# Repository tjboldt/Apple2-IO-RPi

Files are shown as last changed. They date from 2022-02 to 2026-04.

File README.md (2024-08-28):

# Apple2-IO-RPi
Apple II expansion card using a Raspberry Pi for I/O

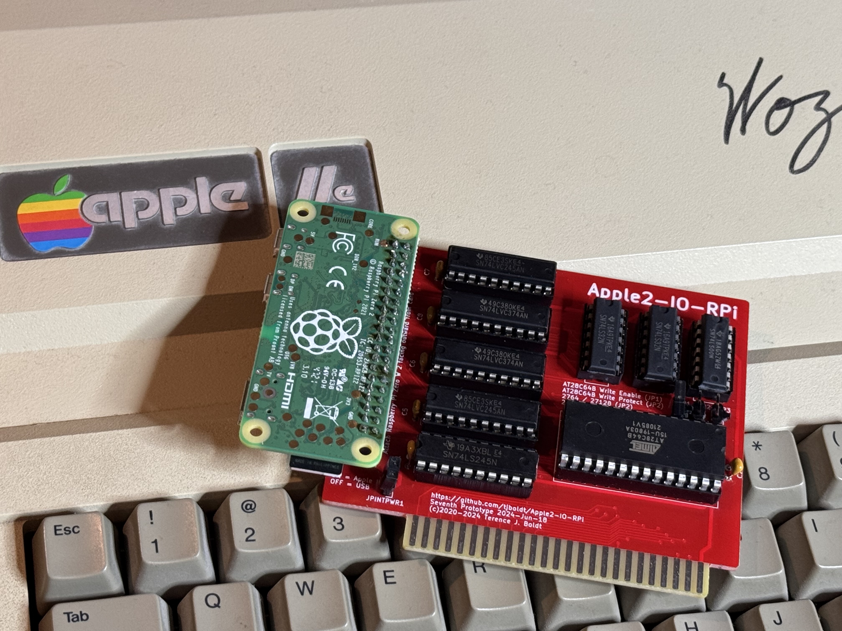
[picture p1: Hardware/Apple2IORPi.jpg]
Image of Board


## Purpose
The purpose of this project is to provide I/O for an Apple II series 8 bit computer via a Raspberry Pi Zero 2 W which is powered by the Apple II expansion bus. This includes using the attached RPi Zero 2 W for it's storage, network and processor to provide new functionality for the Apple II.

## Features
1. Boot message which waits for RPi to be ready
2. ProDOS bootable drive from image stored on RPi
3. Linux bash shell to the RPi from the Apple II including some VT100 support via `-SHELL` from ProDOS
4. Load binary files directly from the RPi to the II (via dynamic virtual drive of current working directory on the RPi)
5. Update Apple II firmware in place from image on RPi (note, this is done per slot)
6. Supports two drive images at the same time
7. Supports "RPI" command from BASIC to execute Linux commands from the command prompt or inside BASIC programs: `10 PRINT CHR$(4);"RPI ls -al /"`

## Project Status

### Classic Hardware
So far, this is still a project and not a finished product. The current prototype is on the seventh revision. I have sold about 60 boards including previous prototypes. There are several hundred in the wild between self made and ones purchased in places like eBay that were made by others. The seventh prototype is functionally equivalent to the sixth other than support for write-protect and reintroducing EPROM support. The fifth revision was similar and compatible with the sixth, other than a new jumper to select internal/external power on the sixth.

The card enables the Apple II to boot from and write to virtual hard drive images stored on the RPi in any slot (except slot 3), execute Linux commands from Applesoft BASIC and run a bash shell with VT100 emulation. The code has very few tests and is incomplete. Note that currently the firmware assumes an 80 column card is in slot 3 and than you have lowercase support. Most development has been done with an enhanced Apple //e with the card in slot 7. If you have other drive controllers earlier in the boot cycle, you can still boot from the Apple2-IO-RPi. For example, if the card was in slot 4, you could type `PR#4` from the BASIC prompt to boot the card. Note that the Raspberry Pi Zero W (and W 2) consume 170 - 250 mA and there is only 500 mA available to all expansion slots according to Apple. It is not recommended to have a lot of other cards in the system at the same time. With the sixth revision of the prototype, it is possible to remove the power jumper and run the RPi on an external USB power source. If configured for external power, note that the card's firmware will hang on boot without USB power on as the latch chips are powered by the 3.3V output of the RPi. 

If you have a problem or idea for enhancement, log an issue [here](https://github.com/tjboldt/Apple2-IO-RPi/issues) or start a [discussion](https://github.com/tjboldt/Apple2-IO-RPi/discussions/categories/general). I recommend starring/watching the project for updates on GitHub. You are welcome to fork the project and submit pull requests which I will review. The latest version has an in-memory virtual drive representing current working directory in Linux for ease of copying files between Linux and ProDOS when the drive 1 is not specified as a file.

### Pico Hardware
Ralle Palaveev has a version of the hardware that uses a RPi Pico to handle firmware and communications to the host over USB. This uses Oliver Schmidt's PIO code.

## Roadmap
See [List of issues tagged roadmap](https://github.com/tjboldt/Apple2-IO-RPi/issues?q=is%3Aissue+is%3Aopen+label%3Aroadmap+author%3Atjboldt) 

## Setup on classic hardware
[Setup card from scratch](/ClassicSetup.md)

[Update to latest](https://github.com/tjboldt/Apple2-IO-RPi/discussions/65)

## Setup on Pico based hardware
[Setup card with Pico hardware](/PicoSetup.md)

## Contributions/Thanks
- Hans Hübner ([@hanshuebner](https://github.com/hanshuebner)) for help cleaning up schematics
- Scott ([@figital](https://github.com/figital)) for assembling early prototypes and recommending the AT28C64B chip
- Brokencodez for help with 3.3V conversion
- David Schmenk ([@dschmenk](https://github.com/dschmenk)) for creating his Apple2Pi project, proving that Raspberry Pi can be powered by the Apple II expansion bus
- Wyatt Wong ([@wyatt-wong](https://github.com/wyatt-wong)) for testing with multiple cards
- ([@Abysmal](https://github.com/Abysmal)) for shell and rpi.command testing
- ([@bfranske](https://github.com/bfranske)) for suggesting adding the 5V jumper
- Tim Boldt ([@timboldt](https://github.com/timboldt)) for recommending removing sysfs based GPIO code
- Oliver Schmidt ([@oliverschmidt](https://github.com/oliverschmidt/a2pico)) for writing the Pico PIO and firmware
- Ralle Palaveev ([@rallepalaveev](https://github.com/rallepalaveev)) for Pico hardware design
- Seth Kushniryk ([@sethkush](https://github.com/sethkush)) for providing information on meta key support for shell

## Similar Project
If you prefer having Apple II peripherals control a Raspberry Pi rather than simply using the Raspberry Pi to provide storage, network access and processing to the Apple II, have a look at David Schmenk's excellent [Apple2Pi](https://github.com/dschmenk/apple2pi) project. I am often asked about differences between these two projects. They are similar in some ways but essentially opposite. The Apple2Pi is meant for the primary machine to be the RPi, using the Apple II for it's peripherals. The Apple2-IO-RPi is meant to have the Apple II as the primary machine and just use the RPi for its processing, storage and network.

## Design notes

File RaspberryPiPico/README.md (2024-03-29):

The setup.sh and build.sh are here for convenience of building the Pico code directly on the RPi Zero 2 W attached to the Apple II.

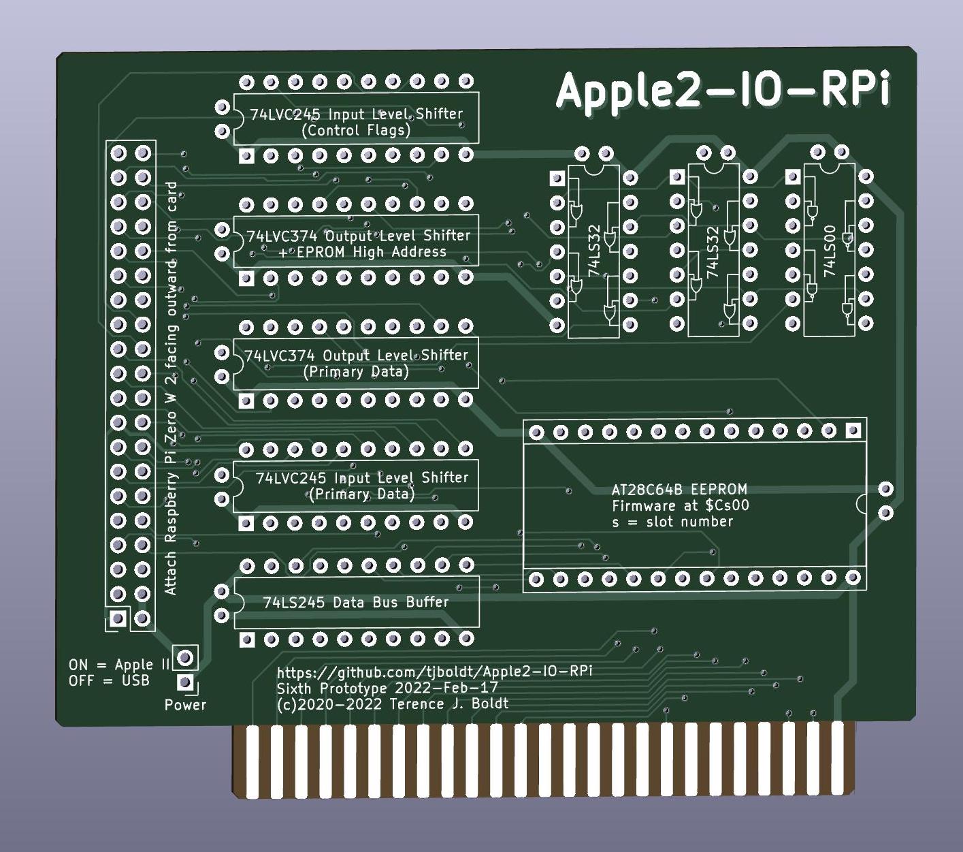
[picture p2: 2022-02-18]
Hardware/Apple2IORPi_PCB.jpg

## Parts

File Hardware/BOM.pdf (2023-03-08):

### Apple2-IO-RPi v5/v6 Bill of Materials

Part | Quantity | Supplier Part # | Supplier
74LS32 | 2 | 595-SN74LS32N | Mouser
74LS00 | 1 | 595-SN74LS00N | Mouser
74LS245 | 1 | 595-SN74LS245N | Mouser
74LVC245 | 2 | 595-SN74LVC245AN | Mouser
74LVC374 | 2 | 595-SN74LVC374AN | Mouser
28C64B | 1 | 556-AT28C64B15PU | Mouser
0.1µF Capacitor | 9 | 594-K104K15X7RF5TH5 | Mouser
2x20 GPIO Female Header | 1 | 2222 | Adafruit
14 Pin DIP Socket | 3 | 571-1-2199298-3 | Mouser
20 Pin DIP Socket | 5 | 571-1-2199298-6 | Mouser
28 Pin DIP Socket | 1 | 571-1-2199299-2 | Mouser

1

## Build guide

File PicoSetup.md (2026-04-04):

## Setup starting from scratch
This is for the A2Pico board (https://github.com/oliverschmidt/a2pico)
1. DIY instructions and PCB coming but it is recommended to buy a board from Ralle Palaveev
2. Update the Pico firmware using the .uf2 file matching your hardware from https://github.com/tjboldt/Apple2-IO-RPi/releases/latest
3. Attach Raspberry Pi Zero 2 W with a micro USB OTG cable
4. Install [Raspberry Pi OS](https://www.raspberrypi.org/software/) on microSD card using a modern computer
    1. Use Raspberry Pi Imager
    2. Click "Choose OS"
    3. Select Other => "Raspberry Pi OS Lite (64 bit)" for the Zero 2 W
    4. Click on the gear icon in the bottom right
    5. Enable ssh
    6. Set password
    7. Configure wifi
    8. Set locale settings  
6. Put microSD card in the RPi
7. Install the expansion card into the Apple II
8. Power on the Apple II
9. Use `ssh` to connect to the RPi using the password you configured
10. `wget --no-cache -O - https://raw.githubusercontent.com/tjboldt/Apple2-IO-RPi/main/RaspberryPi/setup.sh | bash -s 1`

## Options
You can support two drives and change their drive images.
1. Modify the `ExecStart` line in `/etc/systemd/system/apple2driver.service` and make it something like the following: `ExecStart=/home/pi/Apple2-IO-RPi/RaspberryPi/apple2driver/apple2driver -cdc=true -d1 /home/pi/Apple2-IO-RPi/RaspberryPi/Apple2-IO-RPi.hdv -d2 /home/pi/Apple2-IO-RPi/RaspberryPi/TotalReplay401.hdv`
2. `sudo systemctl daemon-reload`
3. `sudo systemctl restart apple2driver.service`

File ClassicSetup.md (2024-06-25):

## Setup starting from scratch
1. Have PCBs made from [PCBWay](https://www.pcbway.com/project/shareproject/Apple2_IO_RPi_v7_65457a66.html) or from the gerber and drill files in the Hardware folder or email me for a blank or fully assembled board
2. Solder chips, header and capacitors in place
3. If you have an EPROM programmer, it is preferred to pre-populate the EEPROM with the contents of AT28C68B.bin
4. Attach Raspberry Pi Zero 2 W facing outward from the card
5. Install [Raspberry Pi OS](https://www.raspberrypi.org/software/) on microSD card using a modern computer
    1. Use Raspberry Pi Imager
    2. Click "Choose OS"
    3. Select Other => "Raspberry Pi OS Lite (64 bit)" for the Zero 2 W
    4. Click on the gear icon in the bottom right
    5. Enable ssh
    6. Set password
    7. Configure wifi
    8. Set locale settings  
6. Put microSD card in the RPi
7. Install the expansion card into the Apple II
8. Power on the Apple II
9. Only if you didn't have an EPROM programmer in step 3, install firmware with utility (can be found on Apple2-IO-RPi.hdv drive image in the release on GitHub) 
10. Use `ssh` to connect to the RPi using the password you configured
11. `wget --no-cache -O - https://raw.githubusercontent.com/tjboldt/Apple2-IO-RPi/main/RaspberryPi/setup.sh | bash`

## Options
You can support two drives and change their drive images.
1. Modify the `ExecStart` line in `/etc/systemd/system/apple2driver.service` and make it something like the following: `ExecStart=/home/pi/Apple2-IO-RPi/RaspberryPi/apple2driver/apple2driver -d1 /home/pi/Apple2-IO-RPi/RaspberryPi/Apple2-IO-RPi.hdv -d2 /home/pi/Apple2-IO-RPi/RaspberryPi/TotalReplay401.hdv`
2. `sudo systemctl daemon-reload`
3. `sudo systemctl restart apple2driver.service`

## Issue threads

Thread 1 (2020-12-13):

RPi service hangs if call interrupted

tjboldt, 2020-12-13:
If you reset the Apple II during a read or write operation, the RPi side hangs waiting for that to complete instead of timing out.

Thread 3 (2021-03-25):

GetTimeCommand called on each ReadBlock which is slow

tjboldt, 2021-03-25:
Ideally there should be a proper ProDOS clock driver but at a minimum, the GetTimeCommand should be called less frequently. Perhaps only reading block 0002 which the root directory is stored.

```
; ProDOS Read Block Command
ReadBlock:
 ldy #$00 ;Get the current time on each block read for now
 lda #GetTimeCommand
 jsr SendByte
getTimeByte:
 jsr GetByte
 sta $bf90,y
 iny
 cpy #$04
 bne getTimeByte
 lda #ReadBlockCommand ;read the block after setting the clock
```

tjboldt, 2021-05-10:
The firmware was updated to only get the time on reading block $0002.

Closed 2021-05-10.

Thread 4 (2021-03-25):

Slow power-on startup

tjboldt, 2021-03-25:
The Raspberry Pi needs to be configured to boot faster. Currently there is no startup optimization done.

tjboldt, 2022-02-09:
The boot time has been significantly reduced by using a Raspberry Pi Zero W 2 as well as the new instructions to disable unnecessary services in the setup: https://github.com/tjboldt/Apple2-IO-RPi/discussions/63

Closed 2022-02-09.

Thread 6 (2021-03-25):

Rpi.Command is hard coded for slot 5 operation

tjboldt, 2021-03-25:
This code was written in the mini assembler on an enhanced Apple //e as a quick test so it was lazily hard coded for slot 5. This should be updated to detect the card automatically in any slot.

tjboldt, 2021-03-28:
Command was removed and code incorporated into the firmware

Closed 2021-03-28.

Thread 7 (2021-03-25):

Firmware updater for AT28C64B missing

tjboldt, 2021-03-25:
The firmware updater code was written in the mini assembler and not saved back to this repo. This needs to be rewritten and committed.

tjboldt, 2021-05-09:
The firmware updater has been written in Applesoft BASIC to read the firmware binary and write it to any slot that the card is in. This is now part of the drive image.

Closed 2021-05-09.

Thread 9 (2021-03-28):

Card hangs if accessed before RPi is ready on power-up

tjboldt, 2021-03-28:

tjboldt, 2021-03-30:
This appears to be stuck on the Apple II side as a reboot of the II resolves it. The start up sequence in the menu firmware will need to be altered to handle the case where the RPi starts up with its read line low which confuses the II code into thinking the RPi is ready when it's not.

tjboldt, 2021-06-01:
Fixed by commit 460440ea4299d5a2145dea092fd77cbab4f628d6

Closed 2021-06-01.

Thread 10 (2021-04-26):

Programming the eeprom via an apple 2

resend2, 2021-04-26:
Exploring TJBoldt's Applesoft writer for programming the eeprom to apple2-io-rpi v4.  Any objection if I attach/share your applesoft code and my noob-to-project notes here, Terence?

resend2, 2021-04-26:
Ah, found equivalent code in Apple2-IO-RPi.hdv, so I'm hoping you wouldn't mind.

Are lines 30 and 40 (peek and if a<>b) verifying the write and 10ms delay are done?

tjboldt, 2021-04-26:
Yes, the source for writing the firmware is on the drive image. It has a bug though that it doesn't set the current firmware page so it's hit and miss as to which page it writes to. It also doesn't include the entire firmware, only the first page. I will update it one night after work this week. The firmware for the AT28C64 has four pages of firmware for each slot. Even after fixing the bug, the code to update the firmware will only work for the slot that it is in.

tjboldt, 2021-05-09:
See https://github.com/tjboldt/Apple2-IO-RPi/issues/7

The drive image has been updated to include the Applesoft BASIC program UPDATE.FIRMWARE along with the firmware binary. If you have a working system, you can run this directly from the Apple2-IO-RPi to update the firmware. If not, use other Apple II tools to copy the files to your Apple II and run it there.

Closed 2021-05-09.

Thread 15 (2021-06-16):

Apple ii/ii+ Uppercase issue

Moddkid, 2021-06-16:
cannot execute linux commands with uppercase only computers.  need workaround for this?

tjboldt, 2021-06-16:
Thanks for bringing this to my attention. The board was developed with an enhanced //e. The current firmware makes some assumptions that lowercase is supported and even expecting an 80 column card to be in slot 3. Although it would be hard to see with uppercase only character ROM, it might be possible to alternate between uppercase and lowercase using the ESC key in the input. This will require a custom input routine instead of the standard ROM based one currently used. This could be a challenge for firmware space on the card. Another alternative would be to always convert text to lower case if a ][ or ][+ is detected. Most Linux commands are lowercase but this won't always work. More of a temporary workaround. Another possibility is to make the command execution a program on the drive image as this allows for enough code space for a custom input routine.

tjboldt, 2021-10-14:
Reopening as only a workaround was implemented and not full shift-key-mod support.

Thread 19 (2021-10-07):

Add clock driver instead of force set time on block 0002 read

tjboldt, 2021-10-07:
Currently the ProDOS time is force set on read of block 0002. There should be a proper ProDOS clock driver created instead.

tjboldt, 2021-11-12:
This could be setting the address stored at $BF07,$BF08 to point to an entry point in the firmware. The code to set the time already exists so this would be just fixing the entry point to work regardless of firmware page selected (like the drive access) and then setting the pointer in ProDOS.

Closed 2024-04-18.

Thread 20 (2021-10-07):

Hangs on long running Linux commands

tjboldt, 2021-10-07:
If you run a command that doesn't exit, the response never comes back because the way commands work now is to launch a process, wait for exit and return the standard output. If the command doesn't exit, the driver effectively hangs waiting for the command.

Closed 2021-10-12.

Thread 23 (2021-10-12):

Bug: Wifi setup locked to Canada region

tjboldt, 2021-10-12:
When configuring wifi, there is no way to specify country code and it is hard coded to CA for Canada.

tjboldt, 2021-11-27:
Note: now that an interactive Shell is available, it is possible to run ‘sudo vim /etc/wpa_supplicant/wpa_suplicant.conf’

Closed 2021-12-31.

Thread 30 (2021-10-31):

Bug: Some commands do not exit properly when cancelled with pending output

tjboldt, 2021-10-31:
Example, run 'ls' on a large directly and then press ^C. The next command run will continue the output from the previous command.

tjboldt, 2021-11-06:
Thread to read stderr was removed and all commands use 2>&1 to redirect stderr to stdout

Closed 2021-11-06.

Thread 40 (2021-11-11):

Bug: Interactive shell apps like vim put driver in bad state

tjboldt, 2021-11-11:
**Describe the bug**
When running vim from the SHELL application, sometimes rapidly scrolling up and down through a file can cause the driver to get into a bad state and also put the target application like vim in a bad state. This appears to be caused by byte write failures while reading bytes. Bidirectional communications needs to be improved.

**To Reproduce**
Steps to reproduce the behavior:
1. Boot ProDOS
2. Type `-SHELL`
3. Type `vim Apple2-IO-RPi/RaspberryPi/apple2driver/driver.go`
4. Rapidly scroll up and down through the file with the J and K keys
5. Keep doing this until the screen messes up and gives errors

**Expected behavior**
Interactive applications run in the shell should work without failing.

**Hardware:**
- Host computer: Enhanced Apple //e
- Additional cards: 80 column
- Apple2-IO-RPi Version (prototype 5)
  - Origin (handmade by the project author)
  - When was firmware last updated (current)

**Software:**
- Latest software under development

**Additional context:**
This was noticed after VT100 emulation development was started.

Closed 2021-11-25.

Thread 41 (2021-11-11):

Bug: Interactive applications run from the shell missing cursor

tjboldt, 2021-11-11:
**Describe the bug**
When running interactive applications like vim from the SHELL application, the cursor is not visible.

**To Reproduce**
Steps to reproduce the behaviour:

1. Boot ProDOS
2. Type -SHELL
3. Type vim Apple2-IO-RPi/RaspberryPi/apple2driver/driver.go
4. Note that the cursor is missing

**Expected behaviour**
Interactive applications run in the shell should show the cursor.

**Hardware:**
- Host computer: Enhanced Apple //e
- Additional cards: 80 column
- Apple2-IO-RPi Version (prototype 5)
  - Origin (handmade by the project author)
  - When was firmware last updated (current)

Software:
Latest software under development

Additional context:
This was noticed after VT100 emulation development was started.

tjboldt, 2021-11-21:
With the latest changes with TTY support added and the SHELL application using the new shell command to launch bash, the cursor is always gone, not just inside interactive apps.

Closed 2021-11-25.

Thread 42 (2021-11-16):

SOIC PCB version

bfranske, 2021-11-16:
**Is your feature request related to a problem?**
Yes, DIP parts (especially 74LS245 and AT28C64B) are out of stock from many suppliers with very long lead times.

**Describe the solution you'd like**
SOIC footprint version of the PCB

tjboldt, 2021-11-20:
Indeed it seems that components are increasingly difficult to source. I'm working on a hybrid board that will take either DIP or SOIC so any chip can be of either package type depending on availability.

pmansell20, 2021-12-14:
Just built 2 of these, no 74LS245 DIP in stock anywhere, so used 74HCT245, no issues on ROM 1 IIGS or Laser 128EX so far.
The T in the IC part no is important, HCT parts have switching thresholds similar to LS (that's what the data sheets say anyway).

FWIW No problems to get the AT28C64B DIP in Australia - element14 show them in stock (although they take a couple of days to come into the local warehouse). But there's not a lot of them.

In any case thanks for the easy storage solution for the II's.

Hubidrei, 2022-09-15:
So i could source  all components but the 74LVC374, only found them on Mouser but shipping is too expensive. So i now tried with 74AC374. They seem to work in my BASIS108, will have to do more long time tests.

tjboldt, 2024-08-21:
Note that there is a SOIC version of the A2Pico card which is now compatible with this project.

https://github.com/rallepalaveev/a2pico/tree/main/A2Pico.v2.7

Closed 2024-08-21.

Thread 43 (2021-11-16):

Add 5v disable jumper to PCB

bfranske, 2021-11-16:
**Is your feature request related to a problem? Please describe.**
No.

**Describe the solution you'd like**
Add a jumper position (or switch position) to disconnect the 5v supply line to the Pi.

**Additional context**
This would allow use of Pis which require more power than the Apple 2 bus can provide by allowing them to be powered separately.

tjboldt, 2021-11-20:
The original intention of this project was to make a standalone board. From the Apple II's perspective, it should be a simple peripheral card, not a separate computer with power cables running to it. That said, it's not difficult to add jumpers to the design. The previous revision of the board had jumpers for selecting a 27C256 EPROM or AT28C64B EEPROM. Given the current scarcity of Zero W and Zero W 2 variants of the Raspberry Pi, it would be nice to have the flexibility to use other boards with external power. The jumpers can be added along with the new hybrid SOIC/DIP board. Note that full sized Raspberry Pi boards do not physically fit with the Apple II's lid closed so you'll need a 40 pin ribbon cable to move the RPi off the card.

bfranske, 2021-11-21:
Recognizing there are some simplicity of assembly reasons for not requiring a jumper alternatives to a full scale jumper could be a spot for a 0 ohm SMD resistor, for a through hole wire link which could be cut, or a spot for a jumper which has a trace between the pads which could be cut through but later replaced with a jumper or a wire link if the user desired to re-connect.

dlxmax, 2022-01-24:
Along the lines of using a more power-hungry rpi, you can undervolt, underclock, and disable some unnecessary functionality to significantly reduce power draw.
https://www.reddit.com/r/raspberry_pi/comments/aki1is/reducing_power_of_the_raspberry_pi_3_b/

wyatt-wong, 2022-02-12:
> Along the lines of using a more power-hungry rpi, you can undervolt, underclock, and disable some unnecessary functionality to significantly reduce power draw. https://www.reddit.com/r/raspberry_pi/comments/aki1is/reducing_power_of_the_raspberry_pi_3_b/

I think the WiFi and BlueTooth functions is required for the time being, especially WiFi for connecting to the Internet. I am not use if @tjboldt would like to BlueTooth functionality or not in existing or future updates.

tjboldt, 2022-02-12:
Wifi is required to set the clock, get code updates, allow ssh to work etc. but the current setup instructions for setting up from scratch do disable Bluetooth.

tjboldt, 2022-02-16:
Some notes on using external power:

1. The power must not be connected when inserting or removing the card from the slot
2. Since the latch chips controlling firmware pages run on 3.3V power supplied by the RPi, the card will hang on boot if the RPi is not powered
3. In testing a v5 board with a power trace cut, there were occasional boot failures while using external power but could be a coincidence
4. Using a USB power meter, the RPi Zero W 2 was typically drawing 170 mA but occasionally peaked around 250 mA, confirming the theory that when using internal power, the card uses up about half of all available power to all slots which Apple claims is a maximum of 500 mA. External power is likely required for systems with other power hungry cards installed.

tjboldt, 2022-02-18:
Created a new sixth prototype with 5V jumper

Closed 2022-02-18.

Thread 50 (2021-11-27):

Bug: Shell app hard coded to slot 7

tjboldt, 2021-11-27:
The shell app is hard coded to work with slot 7 only.

**To Reproduce**
Steps to reproduce the behavior:
1. Put card in any slot other than 7
2. Type 'SHELL’
3. Hangs

**Expected behavior**
Should work in any slot (auto detect or prompt for slot).

**Hardware (please complete the following information):**
- Apple //e but same with all II’s
- Happens with any configuration

**Software (please complete the following information):**
- Latest in development

Closed 2021-12-31.

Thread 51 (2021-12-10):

Add Nibble/DSK Image support

bfranske, 2021-12-10:
**Is your feature request related to a problem? Please describe.**
Depends on how you define problem :) The problem is Apple2-IO-RPi does not currently support Nibble/DSK images which are useful for software which can't be easily loaded onto a ProDOS volume.

**Describe the solution you'd like**
Implement Nibble/DSK support for DOS 3.3 images, see suggestions on method below.

**Additional context**
I'm a bit naive with Apple II design...but I think this is doable with software/firmware only changes? Did some research and it looks like an approach similar to the open source [Pseudo-Disk II](http://alexfreed.com/FPGApple/pseudodisk.html) would be possible. That project supports both a ProDOS and Nibble mode. The general approach to Nibble support is described as "Boot code identical to one found in a standard DISK II controller card is mapped into the Cx00-CxFF memory space. AVR interprets reads from the addresses responsible for disk operation. For example it notices attempts to position the head and adds a offset to the beginning of the image." In the case of the Apple2-IO-RPi it would seem that the Boot ROM could load the Disk II card code into memory, then a driver on the Pi side (instead of the AVR used by Pseudo-Disk II) could interpret the calls for disk operation and read/write from a Nibble (or DSK) file.

tjboldt, 2021-12-10:
The Raspberry Pi running Linux is not particularly well suited for realtime. The Pseudo-Disk II concept really requires different hardware with a microcontroller. This request would be a good candidate for a Raspberry Pi Pico but I believe someone else is already working on a project for that. This project was designed for command and response, the Apple II sending commands and the Raspberry Pi responding. The focus going forward is to increase what those commands are from the existing ReadBlock, WriteBlock, Execute, Shell, LoadFile etc. and add on things like LoadImage, Compile, WGet, VNC, etc.

tjboldt, 2022-01-14:
Moved to Discussions here: https://github.com/tjboldt/Apple2-IO-RPi/discussions/68

Closed 2022-01-14.

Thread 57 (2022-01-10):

Bug: RPI hangs after exiting SHELL

Abysmal, 2022-01-10:
Description
When one runs and exits the SHELL program, further RPI commands seem to hang.

To Reproduce
Steps to reproduce the behavior:

- run -SHELL
- perform anything
- Exit shell back to ]
- preform RPI command and the system doesn't seem to respond and hangs

Expected behaviour
- RPI to resume functionality

Hardware:

Host computer ( Platinum Apple //e)
Additional cards ( Disk II in 6, 80 column in 0, serial in 4, mouse in 1, uthernet in 2 )
Apple2-IO-RPi Version ( not sure of revision ) - Slot 7
Origin (Self-made)

Software:

Latest software
Additional context
None.

Closed 2022-01-11.

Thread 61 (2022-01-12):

Support for Reactive Micro RAMWorks IIII v1.2 and A2Heaven Ramworks III VGA extender ?

wyatt-wong, 2022-01-12:
Does Apple 2 IO RPi board support Reactive Micro RAMWorks IIII v1.2 (which offers 80 column) and A2Heaven Ramworks III VGA extender ?

Reactive Micro RAMWorks IIII v1.2
https://www.reactivemicro.com/product/ramworks-iiii/

A2Heaven Ramworks III VGA extender
http://www.a2heaven.com/webshop/index.php?rt=product/product&product_id=152

tjboldt, 2022-01-12:
I don’t have either of those to test with but it shouldn’t be a problem as the 80 column firmware is built into the Apple //e ROM. As long as the total current draw on the slots and power supply isn’t too high, it should in theory be fine. My SHELL command is calling $c300 to activate the 80 column mode and uses the standard soft switches for 80 column text page RAM access.

wyatt-wong, 2022-01-12:
When is the board available for sale ?

tjboldt, 2022-01-13:
Closing this issue as it was moved to the Discussions section.

Closed 2022-01-13.

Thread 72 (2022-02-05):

Unable to boot up Apple 2 IO RPi in Platinum IIe Slot 4

wyatt-wong, 2022-02-05:
I found Apple 2 IO RPi was unable to boot up when I installed it in Slot 4, here is my hardware configuration:

Platinum IIe (US version)

Slot 7 - A2Heaven Apple II VGA Scaler (https://a2heaven.com/webshop/index.php?rt=product%2Fproduct&product_id=142)
Slot 6 - Apple 5.25 Disk Controller Card with DB19 connector
Slot 5 - Apple II 3.5 Disk Controller Card with DB19 connector (original one, NOT the clone version from Reactive Micro)
Slot 4 - Empty
Slot 3 - VidHD
Slot 2 - Empty
Slot 1 - Apple II Super Serial Card II
Auxiliary Slot - 80-Column Card

No Slot Clock v1.1 from Manila Gear

tjboldt, 2022-02-05:
My first guess would be too much current draw. Does it boot with other cards removed?

wyatt-wong, 2022-02-05:
> My first guess would be too much current draw. Does it boot with other cards removed?

Check my other post. I guessed it was not due to many cards installed, but probably it could not boot up due to I installed it to Slot 4 instead of Slot 5-7. But normally Apple II will auto scan the slots from Slot 7 back to Slot 1, so it can support a maximum of 14 Disk Drives with 7 Disk ][ or Apple 5.25 Disk Controller Cards installed to all the slots.

tjboldt, 2022-02-05:
It should boot in any slot as long as it has enough power. The Apple II bus is limited to 500 mA and the card with RPi draw about 200 mA. It's also possible that you got an EEPROM from one of my development boards which could have older or incorrect firmware. If you can get the AT28C64.BIN file and UPDATE.FIRMWARE onto another drive, you can reinstall the firmware for slot 4. The firmware is programmed per slot.

tjboldt, 2022-02-05:
Note that with related issue of it crashing on boot in other slots, I strongly suspect it's current draw. Try with all other cards removed except 80 column card. If it's still failing, it could be a damaged card.

wyatt-wong, 2022-02-05:
> It should boot in any slot as long as it has enough power. The Apple II bus is limited to 500 mA and the card with RPi draw about 200 mA. It's also possible that you got an EEPROM from one of my development boards which could have older or incorrect firmware. If you can get the AT28C64.BIN file and UPDATE.FIRMWARE onto another drive, you can reinstall the firmware for slot 4. The firmware is programmed per slot.

I will try to update the firmware to the EEPROM and see if I can boot it up in slot 4 or not.

tjboldt, 2022-02-05:
If you have an EPROM programmer, you can reprogram the entire chip with contents of AT28C65B.bin. UPDATE.FIRMWARE is an AppleSoft BASIC program for writing the firmware in-system for people who don't own an EPROM programmer. When programming in-system, it only writes the firmware for the slot that the card is in. With an EPROM programmer, you are writing the full firmware for all slots.

wyatt-wong, 2022-02-05:
> If you have an EPROM programmer, you can reprogram the entire chip with contents of AT28C65B.bin. UPDATE.FIRMWARE is an AppleSoft BASIC program for writing the firmware in-system for people who don't own an EPROM programmer. When programming in-system, it only writes the firmware for the slot that the card is in. With an EPROM programmer, you are writing the full firmware for all slots.

Since I cannot bootup Apple 2 IO RPi probably, I have only one choice to re-programme the whole EEPROM AT28C64B

tjboldt, 2022-02-05:
I still suspect power issues rather than firmware. Before reprogramming the firmware, try removing all the other cards from the system and see if it works on its own.

wyatt-wong, 2022-02-05:
> I still suspect power issues rather than firmware. Before reprogramming the firmware, try removing all the other cards from the system and see if it works on its own.

Initially when I put it in slot 4, it didn't boot at all. So I have removed the Apple 5.25 Disk Controller from slot 6 and put Apple 2 IO RPi to slot 6 and it failed to boot up successfully.

Removing all the cards for testing is possible but since I have the connectors attached to the backpane of Apple IIe, removing all of them for testing is quite troublesome. I would not try to remove the connectors from the backpane of IIe, but removing all cards without removing the connectors is quite a challenge as I need to ensure the cards will not accidentally fall back into my IIe motherboard and cause a short circuit.

I would like how many cards that other people normally installed in their Apple IIe. If Apple 2 IO RPi couldn't boot up due to too many cards already installed, I think it is an issue that need to tackle.

wyatt-wong, 2022-02-05:
I would try to perform the test the other day and see the result.

tjboldt, 2022-02-05:
Thanks for taking the time to help troubleshoot an in-development prototype. Through the process of elimination, we are determining the issue with your card. It was tested and working before it shipped but it's possible a weak solder joint loosened up during shipping. It's possible that it doesn't work with the particular cards in your system. I'm fairly sure I programmed the EEPROM on that card for all slots but it's possible I mixed up with another EEPROM I was doing development on and in-system programming for slot 7 only. So far about 20 others have successfully used cards that they built themselves or I built for them but that's a pretty small sample rate. If you're not satisfied with the card, you can ship it back for a full refund.

wyatt-wong, 2022-02-06:
After some more testing, I found that it was NOT due to the bad solder joint of the Apple 2 IO RPi Card. I suggest to close this issue. Please refer to the next issue that I report.

tjboldt, 2022-02-06:
Thanks for the update. I will close this issue now.

Closed 2022-02-06.

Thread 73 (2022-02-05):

Apple 2 IO RPi show monitor prompt after loading ProDOS 2.4.2

wyatt-wong, 2022-02-05:
After I removed the Apple 5.25 Disk Controller Card from Slot 6 and installed Apple 2 IO RPi to slot 6, I booted up Platinum IIe and found monitor prompt showed on screen after loading ProDOS 2.4.2. Every time I boot up Apple 2 IO RPi, I got a slightly different screen.

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

On one occasion, the ProDOS 2.4.2 screen was shown forever

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

Due the the Apple 2 IO RPi is very close to the Apple II VGA Scaler, I added a paper in between to avoid short circuit.

tjboldt, 2022-02-05:
Aside from current draw from other cards, the only other thing I can think of that might cause that is bad solder joints. It's a hand assembled prototype and shipped across the world. Try it with no other cards in the system and if it's still failing, I can send you a refund or a replacement.

wyatt-wong, 2022-02-06:
This case happened most probably due to the Apple 3.5 Disk Controller Card was installed in Slot 5, even when there are no Apple 3.5 Disk Drive was attached. I would suggest to close to issue. Please refer to Issue 14 for other findings.

tjboldt, 2022-02-06:
Thanks for the update. Closing issue.

Closed 2022-02-06.

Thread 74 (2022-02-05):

RPI.COMMAND hard coded for slot 7

tjboldt, 2022-02-05:
### What happened?

Executing RPI.COMMAND when the card is in a slot other than slot 7 will fail. It's hard coded to slot 7. It should be made to work in other slots like SHELL has been updated to do.

### Hardware Version

Fifth Prototype (Self-assembled)

### Where are you seeing this problem?

RPI Command

### What computer is this running on?

Apple //e (enhanced / platinum)

wyatt-wong, 2022-02-06:
As you already stated the above bug, I found that executing -RPI.COMMAND when Apple 2 IO RPi was NOT installed in Slot 7,  it immediately returns to the the BASIC prompt. When I executed "RPI a2wifi list", I got a bunch of garbage letters on screen indefinitely.

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

Closed 2022-02-07.

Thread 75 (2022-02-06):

Different cases that Apple 2 IO RPi was unable to boot up

wyatt-wong, 2022-02-06:
### What happened?

Apple 2 IO RPi was unable to boot up in the following cases:

Case 1
When either Apple 5.25 Disk Controller Card or Apple 3.5 Disk Controller Card card was installed in Slot 6 or Slot 5, with Apple 2 IO RPi installed in Slot 4 (and most probably true if Apple 2 IO RPi was installed in Slot 1 or Slot 2, refer to case 2 when Apple 2 IO RPi was installed in Slot 3)

In Case 1, even if no Disk Drive is connected to Apple 5.25 Disk Controller Card and/or Apple 3.5 Disk Controller Card, Apple 2 IO RPi still could not boot up.

### Workaround
Remove Apple 5.25 Disk Controller Card and Apple 3.5 Disk Controller Card from Apple IIe.

Case 2
When Apple 2 IO RPi was installed in Slot 3:

1. With 80 column card installed in auxiliary slot, Apple 2 IO RPi immediately display a BASIC prompt
2. Without 80 column card installed in auxiliary slot, Apple 2 IO RPi will start loading the Raspberry Pi firmware and then showed the ProDOS 2.4.2 splash screen, but then the ProDOS 2.4.2 splash screen will be displayed forever without showing the BASIC prompt.

### Workaround
Do NOT install Apple 2 IO RPi to slot 3 of Apple IIe.

### Hardware Version

Fifth Prototype (Purchased from Terence)

### Where are you seeing this problem?

Boot

### What computer is this running on?

Apple //e (enhanced / platinum)

tjboldt, 2022-02-06:
It makes sense that slot 3 will not work because that space is required for the 80 column firmware. I will update the documentation to note that it should not be installed in slot 3.

The Apple II, as you know, scans from slot 7 down to search for a card with bootable firmware. So in slot 4, the Apple will try to boot from your other drives first. What happens if you have all the cards in place, a 5.25" drive connected with a boot floppy in? Does the computer successfully boot from floppy? After you boot, you could type `PR#4` at the BASIC prompt to boot the A2-IO-RPi and it will start up. Note, if you booted ProDOS 2.4.2 from floppy disk, the A2-IO-RPi drives will be detected even though they were not booted from. The one issue you might have is when ProDOS goes to check the A2-IO-RPi and it wasn't booted from, it may hang the OS while the firmware on the card is waiting for the RPi to start up.

Thanks again for all your help testing.

tjboldt, 2022-02-06:
README has been updated to reflect the fact that this does not work in Slot 3.

wyatt-wong, 2022-02-06:
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

I understand the basic boot mechanism. I was not surprised that Apple 2 IO RPi doesn't boot when it was installed in slot 4, with Apple 5.25 Disk Controller Card and Apple 3.5 Disk Controller Card installed in Slot 6 and Slot 5 respectively. However, I was NOT aware that I can manually booted up the Apple 2 IO RPi by typing PR#n where n is the slot number. It should be mentioned in the documentation if it wasn't there.

However I wasn't sure why issue #73 happens when Apple 2 IO RPi was installed in Slot 6 with Apple 3.5 Disk Controller Card in Slot 5. According to the boot mechanism, Apple 2 IO RPi should boot up successfully because it is installed in a higher slot number (slot #6) than the Disk Controller Card installed in a lower slot number (slot #5).

wyatt-wong, 2022-02-06:
I would also like to mention that I tested the Apple 2 IO RPi card a couple of more times. When Apple II Super Serial Card II and VidHD are installed, they did NOT interfere with Apple 2 IO RPi at all.

In short, Apple 2 IO RPi failed to boot up when
1) A Disk Controller was installed in Apple IIe, regardless of whether it is installed in a lower or a higher slot number than Apple 2 IO RPi ;or
2) If Apple 2 IO RPi was installed in Slot 3 of Apple IIe.

tjboldt, 2022-02-06:
That is unexpected if the A2-IO-RPi was in slot 6 and the 3.5" controller was in slot 5. That should boot. I just tested that configuration now and it came up fine on mine. I usually have the A2-IO-RPi in slot 7 and 5.25" controller in slot 6 along with an extended 80 column card in the aux slot but dug out the other card and switched it around for this test.

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

tjboldt, 2022-02-06:
README.md updated with notes about using PR# to boot the card.

tjboldt, 2022-02-08:
raspi-config is confusing to use with a keyboard even when a monitor and keyboard is directly connected to the RPi. Left and right arrows will change focus to the buttons and space presses the button. See here for more information on this tool: https://www.raspberrypi.com/documentation/computers/configuration.html

wyatt-wong, 2022-02-15:
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

Actually the card you installed in Slot 5 is the Liron Card. I am talking about the Apple 3.5 Drive Controller Card (also known as the Apple SuperDrive Controller Card)

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

tjboldt, 2022-02-15:
I wasn't familiar will all the different versions of the 3.5" drive controllers, just that the card I had is a genuine Apple card and says '3.5" Floppy Disk Drive Interface Card' on it. Indeed, looking it up, it is commonly referred to as the Liron card. The Apple2-IO-RPi does work in slot 1,2,4,5,6 or 7 but appears to be incompatible with the particular cards you have in your system.

tjboldt, 2022-02-15:
There is one more extreme measure that could be taken but it would require cutting a trace on the board and using external power for the RPi. It would only help if the issue is power related as originally suspected but not confirmed. If you did want to go that route, I can attach photos of the modification I tested. Note that not only does it require modifying the hardware, but this has had very limited testing so far. I booted only a few times with this modification and you would need to be careful about not having power connected until after the card is seated in the powered off Apple II.

tjboldt, 2022-02-16:
@wyatt-wong Would it be okay to close this issue? The original problem of not working in other slots has been fixed with a combination of code update in RPI.COMMAND to auto-detect the slot as well as documentation changes in the README.md to indicate that slot 3 is not supported plus instructions for booting with PR# when not the first boot device. The remaining problem of incompatibility with other cards in place is likely related to #43 or if you prefer, we can open a new issue just for card incompatibility.

wyatt-wong, 2022-02-16:
> @wyatt-wong Would it be okay to close this issue? The original problem of not working in other slots has been fixed with a combination of code update in RPI.COMMAND to auto-detect the slot as well as documentation changes in the README.md to indicate that slot 3 is not supported plus instructions for booting with PR# when not the first boot device. The remaining problem of incompatibility with other cards in place is likely related to #43 or if you prefer, we can open a new issue just for card incompatibility.

I think in your tests the Apple 2 IO RPi have "no" issues starting up in any slot except slot 3. However Apple 2 IO RPi still could not startup properly if I have either Apple 5.25 Disk Controller card or Apple 3.5 Drive Controller card or have both cards installed. Anyway I have no comments to close this issue.

wyatt-wong, 2022-02-17:
> I wasn't familiar will all the different versions of the 3.5" drive controllers, just that the card I had is a genuine Apple card and says '3.5" Floppy Disk Drive Interface Card' on it. Indeed, looking it up, it is commonly referred to as the Liron card. The Apple2-IO-RPi does work in slot 1,2,4,5,6 or 7 but appears to be incompatible with the particular cards you have in your system.

Reactive Micro have a clone version of the Apple 3.5 Drive Controller Card, but it is not cheap and I do NOT expect a lot of people own this card.

https://www.reactivemicro.com/product/apple-ii-3-5-drive-controller-card/

I will perform some testing by removing Apple 3.5 Drive Controller Card from Slot 5 and install the Apple 2 IO RPi card to slot 5, with the Apple 5.25 Drive Controlller Card in slot 6 to see if Apple 2 IO RPi can successfully boot up or not. Last time I tried  this and it doesn't work but I can re-confirm it.
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
tjboldt, 2022-02-26:
Thanks @wyatt-wong for this extensive set of tests. Total current draw on the Apple //e's power supply varies depending on the combination of cards installed. While in the Apple2-IO-RPi, the RPi itself is known to draw between 170 mA and 250 mA as per tests using external power and a USB power meter. Pardon the fuzzy photo... It was in an awkward spot when I took the shot and didn't realize it was too close and out of focus.

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

Since the total current available to all cards is 500 mA according to the Apple ][ Reference Manual, there is barely half of current left for other cards. In the design of this card, I made it so there are multiple pages of 256 byte firmware that are selected using the leftover bits on the 74LVC374 that latch communication flags going to the RPi. Because the RPi GPIO operates at 3.3V and the Apple II operates at 5V, that level shifting was necessary. To get 3.3V power to the chip, I used the 3.3V power output from the RPi itself. So if there are power consumption issues to the rather sensitive RPi (or the RPi is not connected or powered in the case of external power configuration), the latch doesn't operate and prevents the firmware from working. You'll either get hangs or weird crashes that you've observed. Sometimes you'll have enough power for the latch to make the firmware work but the RPi itself will crash due to power drops and then you'll see lots of "......" on boot where the Apple II can't communicate with the driver running on the RPi.

Note that the original Apple branded power supplies generally cut out and reset the computer when current draw was too high. Your aftermarket power supply might act differently.

For your system, I'd recommend either choosing a card combination that works for you or using external power. I'm still waiting on blank PCBs to arrive next week but will ship out a new board as soon as I can. I will leave this issue in open state until you can try at least once with external power using the new board. If it works with the previously failing card combinations, I would argue that the power theory is mostly confirmed. Then it's a matter of documentation of when and how to use external power or to recommend using fewer cards in the system.

tjboldt, 2022-04-13:
@wyatt-wong Did you get a chance to test with external power with the card I sent you?

1. Ensure the power is off
2. Take the RPi from the v5 board and install it on the v6 board
3. Remove the power jumper from the v6 board
4. Install the card into your Apple //e along with the other cards that previously conflicted
5. Connect a USB power supply to the micro USB power input on the RPi
6. Power on your Apple //e

Let me know how it goes.

Thanks,
Terence

wyatt-wong, 2022-04-13:
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

No. I haven't tested it yet. But there are 4 consecutive Easter holidays from 15-Apr-2022 and I should have time to do the test.

wyatt-wong, 2022-04-15:
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

> Thanks, Terence

Just a small comment. You may consider to move the power jumper closer near to the SN74LS245N for easier removal

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

wyatt-wong, 2022-04-15:
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

I was unable to startup Apple 2 IO RPi after using external power. I tried to use power from Apple IIe to startup Apple 2 IO RPi and the result failed. I detached the Raspberry Pi Zero 2 W and re-attach it to the Apple 2 IO RPi card, first I tried to use the power from Apple IIe and I was unable to see the text of Apple 2 IO RPi and then stopped without loading. When I used the external USB power, I got similar monitor screen.

I will take out the Raspberry Pi Zero 2 W and test it to make sure it is functional

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

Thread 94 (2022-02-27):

Arrow keys don't work in vi

tjboldt, 2022-02-27:
### What happened?

The arrow keys don't work in vi even though they work in other editors.

Note, this was a common problem years ago with different terminal editors so there was always a workaround to use hjkl keys to navigate. This workaround still applies here. More info on vi usage can be found [here](https://docs.oracle.com/cd/E19253-01/806-7612/editorvi-43/index.html)

Another workaround is to use an alternative editor.
`sudo apt install nano`

### Hardware Version

Fifth Prototype (Self-assembled)

### Firmware Version

000F

### Driver Version

0023 (replaced periph.io with rpio)

### Where are you seeing this problem?

SHELL command

### What computer is this running on?

Apple //e (enhanced / platinum)

hanshuebner, 2022-02-27:
I think instead of implementing a VT100 emulation in the go server, it'd be better to implement a proprietary terminal emulation (maybe based on the apple2e-p terminfo entry and then use tmux or screen for VT100 emulation if required.

Much of the emulation is already handled by the output routine in the Apple ROM, so it'd require only a few commands to be implemented on the server side.  Putting all of the terminal emulation on the Apple side would also not be terribly hard.

```
chrodon 1014_% infocmp -L apple2e-p
#	Reconstructed via infocmp from file: /usr/share/terminfo/61/apple2e-p
apple2e-p|Apple //e via Pascal,
	auto_left_margin, move_standout_mode,
	columns#80, lines#24,
	bell=^G, clear_screen=\014$<100/>, clr_eol=\035$<4/>,
	clr_eos=\013$<4*/>,
	cursor_address=\036%p2%' '%+%c%p1%' '%+%c,
	cursor_down=^J, cursor_home=^Y, cursor_left=^H,
	cursor_up=^_, enter_reverse_mode=^O,
	enter_standout_mode=^O, exit_attribute_mode=^N,
	exit_standout_mode=^N, init_2string=^R^N,
	key_backspace=^H, key_down=^J, key_left=^H, key_right=^U,
	key_up=^K, newline=\r$<100/>, reset_1string=^R^N,
	scroll_forward=^W, scroll_reverse=^V, tab=^I,
```

I'm planning to go this route with my Lisp server, but maybe you like the idea enough :)

tjboldt, 2022-02-27:
The shell app 6502 code already makes use of a lot of the 80 column firmware, with the Go code translating VT100 codes to Apple control codes. It seems a lot of Linux apps send non-compliant codes and even send colour codes not supported by VT100 even when term=vt100 is set. Parsing escape codes is certainly possible in 6502 assembler but it’s much easier to handle in Golang.

hanshuebner, 2022-02-27:
My point is that there is no need to emulate a VT100 at all, because both screen and tmux already do that.  What it takes to use most Linux command-line tools (i.e. vi, emacs, nano, top, trafshow and all the bunch) is to implement a terminal that is described by a terminfo entry, and the apple2e-p terminfo entry is one such example.  My suggestion was that instead of trying to emulate a VT100 faithfully, adding the few escape codes that the apple2e-p terminfo entry defines would not be hard, and remove the requirement to implement everything that the VT100 terminfo entry defines (look at `infocmp -L vt100` to see what this would be).

hanshuebner, 2022-02-27:
BTW:  The `vttest` program is a pretty good tool that helps to see how good a VT100 emulation is.  It does not use terminfo, but really exercises all features of a VT100.  Not all features can even mapped to terminfo capabilities, so full vttest compatibility is probably not something to thrive for.

It is certainly also possible to use a customized terminfo entry for a terminal emulation that only implements some VT100 features.  Terminfo can also be used to define custom screen sizes, but most issues that revolve around the last column in an emulator not behaving as the Linux programs expect them to do have to do with cursor and position behavior at the end of the line.  Again, terminfo provides for capabilities that tell the program whether the cursor wraps and when, so if it is difficult to implement some behavior in a certain environment, a custom terminfo entry might be a clean solution.

Just things to consider.  Sorry if I'm writing things that you already know.

tjboldt, 2022-02-28:
I did try out vttest during development a few months ago. It tests many things that will never work like double sized fonts and 132 columns. The main focus was to have a generally useable shell. So vi/vim work (albeit with hjkl for navigation), nano makes a working substitute for vi, top works, ssh works, even vitetris works. The terminal info is set (to 79x24 to avoid autoscrolling as noted in another issue). I had considered using screen but the method chosen of converting VT100 to Apple 80 column codes (plus a few custom features) was easier to implement.

tjboldt, 2022-03-01:
@hanshuebner I did some looking into it... It appears that not all of the functionality is covered by changing the terminal type to apple2e-p. Apps like vi set the window to a smaller size for scrolling part of the screen. I handle that now by parsing the VT100 commands, make that a special single byte command (plus parameter bytes), read that in my 6502 shell code and set the Apple II window size accordingly. Also, some apps do not honour the terminal type. Even setting terminal type to vt100, they ignore it and send other non-compliant codes. If you do get it working with terminal type apple2e-p, let me know.

hanshuebner, 2022-03-01:
As far as I have understood from comparing the golang and assembly code and the apple2e-p terminfo entry, some of the emulation is handled by the COUT rom code, and some (like absolute cursor positioning and scrolling region handling) is handled by a combination of the golang code (to parse the ANSI escape sequence) and the assembly code (to translate from the simplified commands to actual cursor movement).  The apple2e-p terminfo entry is probably meant to be used for a particular terminal emulator written in (UCSD?) Pascal which does the same thing - Pass most commands to COUT and handle some in Pascal.  Scrolling region support is not defined in the terminfo entry, but it could be added (the vt100 entry has it as `change_scroll_region=\E[%i%p1%d;%p2%dr`).  The apple2e-p entry should only be seen as a starting point, really.

What programs did not honor the `TERM` setting and instead send vt100 codes?  Those are probably new programs which just assume that the terminal is somewhat ANSI compatible, which is a pretty fair assumption to make in most cases nowadays.  However, with tmux or screen, it should be possible to work with these programs even if the terminal emulation is not an ANSI/vt100 derivative.

I went a bit on a tangent with some other retro stuff, but will return to working on the terminal emulation part in the next days and will report what my results are.

tjboldt, 2022-03-01:
Yes, part of it is Golang and part of it is assembler. In Golang, I set the high bit of the output for the Apple II on all regular text and I convert VT100 codes to the equivalent 80 column firmware control codes. When needed, I send special single byte commands of my own (that are high bit clear), followed by a single byte value parameter. For example, setting the top of the window sends "T" and the binary row number. "B" sets the bottom of the window. "H" sets the horizontal tab. "V" sets the vertical tab etc.

It was months ago so I don't recall which programs sent non-VT100 compliant codes when TERM=vt100 but there were a few. In the code, I see I added a workaround for the "top" command since it tries to vtab to row 25 even when ROWS=24.

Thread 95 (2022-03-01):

Push v6 to PCBWay Projects

dlxmax, 2022-03-01:
### What do suggest for improvement?

Please update the files on PCBWay Projects for the sixth prototype.
https://www.pcbway.com/project/shareproject/Apple2_IO_RPi_v5.html

I have the chips on order, so it's time to order PCBs. Would like the latest. Thanks!

maded2, 2022-03-01:
hi,  any chance for you to have both SMD & DIP footprint on the same board, as sourcing the chips is challenge at the moment.

thanks,
eddie

tjboldt, 2022-03-01:
https://www.pcbway.com/project/shareproject/Apple2_IO_RPi_v6_bfa4be82.html

tjboldt, 2022-03-01:
> hi, any chance for you to have both SMD & DIP footprint on the same board, as sourcing the chips is challenge at the moment.
>
> thanks, eddie

Hi Eddie,

Sorry, no, I haven't had time to design a SOIC version yet. The DIP chips are available still but I had to get them from three different suppliers. A SOIC version will likely get designed later this year. This is covered by #42 and now that the sixth revision is up on PCBWay, I will close this issue.

Regards,
Terence

dlxmax, 2022-03-01:
Thanks, Terence!
However, there might be an issue with the fingers on the connector. They're just PCB trace line size as shown on v6, but correct on v5. Is it a rendering issue at PCBWay, or something else?

tjboldt, 2022-03-01:
I checked the gerber files and they are fine but PCBWay is indeed having issues rendering them. This could be from updating to KiCAD 6 from 5.

Closed 2022-03-01.

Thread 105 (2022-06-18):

Documentation update for Raspberry Pi Imager v1.7.2

DaManDOH, 2022-06-18:
## Setup starting from scratch
1. Have PCBs made from [PCBWay](https://www.pcbway.com/project/shareproject/Apple2_IO_RPi_v6_bfa4be82.html) or from the gerber and drill files in the Hardware folder or email me for a blank or fully assembled board
2. Solder chips, header and capacitors in place
3. Attach Raspberry Pi Zero W facing outward from the card
4. Install [Raspberry Pi OS](https://www.raspberrypi.org/software/) on microSD card using a modern computer
    1. Use Raspberry Pi Imager
    2. Click "Choose OS"
    3. Select "Raspberry Pi OS (Other)" => "Raspberry Pi OS Lite (32 bit)"
    4. Click on the gear icon in the bottom right
        1. Enable ssh
        2. Set password
        3. Configure wifi
        4. Set locale settings
5. Put microSD card in the RPi
6. Install the expansion card into the Apple II
7. Power on the Apple II
8. Install firmware with utility (can be found on Apple2-IO-RPi.hdv drive image) or use EPROM programmer with AT28C64B.bin
9. Use `ssh` to connect to the RPi using the password you configured
10. `wget --no-cache -O - https://raw.githubusercontent.com/tjboldt/Apple2-IO-RPi/main/RaspberryPi/setup.sh | bash`

## Options
You can support two drives and change their drive images.
1. Modify the `ExecStart` line in `/etc/systemd/system/apple2driver.service` and make it something like the following: `ExecStart=/home/pi/Apple2-IO-RPi/RaspberryPi/apple2driver/apple2driver -d1 /home/pi/Apple2-IO-RPi/RaspberryPi/Apple2-IO-RPi.hdv -d2 /home/pi/Apple2-IO-RPi/RaspberryPi/TotalReplay401.hdv`
2. `sudo systemctl daemon-reload`
3. `sudo systemctl restart apple2driver.service`

_Originally posted by @tjboldt in https://github.com/tjboldt/Apple2-IO-RPi/discussions/63_

DaManDOH, 2022-06-18:
See menu change:
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

Also includes nested list improvements.

tjboldt, 2023-11-01:
Thanks. I incorporated some of your changes and made some additional changes to support 64 bit on RPi Zero 2 W.

Closed 2023-11-01.

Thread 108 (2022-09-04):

Need clarification

mgederberg, 2022-09-04:
### What do suggest for improvement?

Before I really attempt this one... Of course the jumper would need to be broken and the pi would need a ribbon cable running outside of the Apple IIe with the pi on it's own juice, but can the card handle a pi4? If so, will the GUI run so I can run stuff like emulationstation?

tjboldt, 2022-09-04:
I have never tested with an RPi 4 but in theory it should work using USB power with the jumper removed. The intention of this project is to provide functionality to the Apple II using the RPi as a source of storage, computation and network. If you are looking for an emulator using the Apple II for its devices, you should look at the Apple2Pi project.

mgederberg, 2022-09-05:
Right on TJ... Thanks for the heads up on that. Does your card work with Schmenk's software though?

tjboldt, 2022-09-05:
No, unfortunately, the two cards are incompatible.

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

mgederberg, 2022-09-05:
Yeah and that would make sense based on my understanding that Schmenk's software is dependent on the same serial communication as ADTPro. Your design is independent of that and in a sense a more direct connection if I might say. With that said, it would be a neat enhancement to get remote control of an RPI4 with GUI using your card, I think it might even be faster and more reliable than SSC intermediaries, no?

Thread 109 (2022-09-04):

Boot problem

amazingcobrazil, 2022-09-04:
### What happened?

Even after preparing the card and writing the AT28C64B several times, the card crashes at the message:
Waiting for RPi FW:000F..._
Sometimes it logs into ProDOS, but most of the time I have to log into the OS and give a command: sudo reboot

### Hardware Version

Sixth Prototype (Self-assembled)

### Firmware Version

000F

### Driver Version

0024 (fix VT100 arrow keys)

### Shell Version

000D (added version info)

### Where are you seeing this problem?

ProDOS access

### What computer is this running on?

Apple //e (enhanced / platinum)

tjboldt, 2022-10-09:
Can you see from the logs on the RPi? Is the apple2driver service crashing? Also, be careful with reflashing the AT28C64B as they have a limited number of write cycles. I have worn out a couple of chips during development.

gwortmann, 2023-06-19:
I had the same problem after I set up the RPI Zero WH with the provided script. I solved the issue by starting the installation from scratch with a stable internet connection.

Checked my installation as follows - on Raspbian:
> sudo systemctl --> showed that the apple2driver failed to start
> sudo journalctl -u apple2driver --> told me, that the folder home/pi/apple2-IO-RPi was completely missing

make sure while setting up the image, that you name the user "pi"

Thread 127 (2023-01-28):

Update GPIO library to reduce power consumption

tjboldt, 2023-01-28:
### What do suggest for improvement?

Update GPIO library to reduce power consumption (remove busy-wait loops and use edge triggering)

tjboldt, 2023-11-01:
It looks like this is a current Linux kernel limitation with user mode so changing libraries won't help... Added a fix in #151 to reduce CPU usage by backing off and sleeping

Closed 2023-11-01.

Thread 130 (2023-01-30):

Apple basic hangs when accessing the drive after exiting SHELL

benjamink, 2023-01-30:
### What happened?

After entering the RPi shell via `-SHELL` then exiting the RPi shell any further access to the virtual drives causes the Apple to hang.  A `Control+Reset+Open-Apple` will reboot the Apple & the drive will be accessible again.  Interacting with the virtual drive normally doesn't appear to have any issues.  Only after entering the RPi shell & then exiting are there problems.

### Hardware Version

Fifth Prototype (Purchased from Terence)

### Firmware Version

000F

### Driver Version

0028 (add live drive loading and regeneration)

### Shell Version

000D (added version info)

### Where are you seeing this problem?

Other

### What computer is this running on?

Apple //e (enhanced / platinum)

benjamink, 2023-01-30:
Confirmed that loading `-RPI.COMMAND` & running `rpi uname -a` to access the RPi *DOES NOT* cause the Apple to hang on subsequent access.

benjamink, 2023-01-30:
`apple2drive` logs from exiting RPi shell & running `catalog` from Apple BASIC:

```Jan 29 21:50:54 a2iorpi apple2driver[1539]: stdout closed
Jan 29 21:50:54 a2iorpi apple2driver[1539]: Reset request
Jan 29 21:51:05 a2iorpi apple2driver[1539]: Sending date/time...3D 2E 33 15
Jan 29 21:51:05 a2iorpi apple2driver[1539]: Read block 0002 in slot 7, drive 1...succeeded
Jan 29 21:51:05 a2iorpi apple2driver[1539]: Sending date/time...3D 2E 33 15
Jan 29 21:51:05 a2iorpi apple2driver[1539]: Read block 0002 in slot 7, drive 1...succeeded
Jan 29 21:51:05 a2iorpi apple2driver[1539]: Read block 0006 in slot 7, drive 1...succeeded
Jan 29 21:51:05 a2iorpi apple2driver[1539]: Read block 0007 in slot 7, drive 1...succeeded```

benjamink, 2023-01-30:
Restarting `apple2driver` from the RPi & hitting Control+Reset will drop Apple back to BASIC & the RPi virtual drive will be accessible again.  No Apple reset/reboot required.

benjamink, 2023-01-30:
Found [gellweiler/errgotrace](https://github.com/gellweiler/errgotrace) & tried it on the current code.  I don't understand if this is useful but these are the lines in the log output when exiting the RPi shell:

```
Jan 29 22:20:22 a2iorpi apple2driver[4634]: stdout closed
Jan 29 22:20:22 a2iorpi apple2driver[4634]: Reset request
Jan 29 22:20:23 a2iorpi apple2driver[4634]: 2023/01/29 22:20:23 [ERRGOTRACE] a2io.A2Gpio.WriteByte: timed out writing byte -- read stuck high
Jan 29 22:20:23 a2iorpi apple2driver[4634]: 2023/01/29 22:20:23 [ERRGOTRACE] a2io.A2Gpio.ReadByte: timed out reading byte -- write stuck high
Jan 29 22:20:23 a2iorpi apple2driver[4634]: 2023/01/29 22:20:23 [ERRGOTRACE] a2io.readCharacter: timed out reading byte -- write stuck high
Jan 29 22:20:23 a2iorpi apple2driver[4634]: 2023/01/29 22:20:23 [ERRGOTRACE] a2io.A2Gpio.ReadCharacter: timed out reading byte -- write stuck high
Jan 29 22:20:24 a2iorpi apple2driver[4634]: 2023/01/29 22:20:24 [ERRGOTRACE] a2io.A2Gpio.ReadByte: timed out reading byte -- write stuck high
Jan 29 22:20:24 a2iorpi apple2driver[4634]: 2023/01/29 22:20:24 [ERRGOTRACE] a2io.A2Gpio.ReadByte: timed out reading byte -- write stuck high
Jan 29 22:20:24 a2iorpi apple2driver[4634]: 2023/01/29 22:20:24 [ERRGOTRACE] a2io.readCharacter: timed out reading byte -- write stuck high
Jan 29 22:20:24 a2iorpi apple2driver[4634]: 2023/01/29 22:20:24 [ERRGOTRACE] a2io.A2Gpio.ReadCharacter: timed out reading byte -- write stuck high
```

tjboldt, 2023-01-30:
The errors that are not normally logged are intentionally not logged. It's a busy wait loop so the timeout waiting for a byte is normal. That said, it looks like the SHELL app sends a reset while the RPi is still in the process of shutting down its side. A less than optimal way to prevent this could be having the SHELL app wait a second before sending the reset command after receiving a null terminator from the RPi. This will have the side effect of a delay on exit. Ideally the RPi would block reads until it is finished shutting down the shell code.

benjamink, 2023-01-31:
Awesome!  Confirmed fixed!

Closed 2023-01-31.

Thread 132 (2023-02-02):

Hangs after a2drive load

omigeot, 2023-02-02:
### What happened?

(it might be version 0029 instead of 0028, I did git pull very recently)

Trying to load an hdv file on drive 2, as per the a2drive command example. The command never returns nor gives control back in any way. Tried on big .hdv files from the internet, but it works the same on an empty image created with ProDOS Utilities right on the Pi.

### Hardware Version

Sixth Prototype (Purchased from Terence)

### Firmware Version

000F

### Driver Version

0028 (add live drive loading and regeneration)

### Shell Version

000D (added version info)

### Where are you seeing this problem?

RPI Command

### What computer is this running on?

Apple IIgs

tjboldt, 2023-02-03:
Apparently I never finished that portion of the code. I will fix that on the weekend. Thanks for bringing it to my attention.

Closed 2023-02-05.

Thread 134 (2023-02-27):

in schematics C value is not set for C3, C4 and C9

JPT77, 2023-02-27:
### What do suggest for improvement?

Please set to 100n

btw, I ordered 10 boards via your PCBway link. Let's see if I can make them work.

Closed 2023-03-01.

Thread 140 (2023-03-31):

RaspberryPi/setup.sh update apt before installing

JPT77, 2023-03-31:
### What happened?

setup script failed, because it wanted to install a git version that wasn't available in the repo any more.

please add an apt update before installing anything... or just check if any apt install failed before continuing.
and probably an apt upgrade?

since firmware, driver etc do not apply to this problem, ignore them please.
it's recent bullyseye raspiOS 32 bit light.

thanks

### Hardware Version

Sixth Prototype (Self-assembled)

### Firmware Version

000F

### Driver Version

0028 (add live drive loading and regeneration)

### Shell Version

000D (added version info)

### Where are you seeing this problem?

Other

### What computer is this running on?

Apple II+

Closed 2023-04-04.

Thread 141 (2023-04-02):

apple2driver draws 100% cpu

JPT77, 2023-04-02:
### What happened?

Hi,
apple2driver draws 100% CPU which makes the single core zero extremely slow. and heats the zero and some 74xx.

this is when Apple2-IO-Rpi is not connected to the zero:
```
Read block 0101 in slot 0, drive 1...failed can't write byte while byte is incoming
Read block 0101 in slot 0, drive 1...failed timed out writing byte -- read stuck low
... repeated over and over
```

and this is when working fine, but still drawing 100% cpu

```
Read block 0002 in slot 5, drive 1...succeeded
Sending date/time...7F 2E 26 0D
Read block 0002 in slot 5, drive 1...succeeded
Sending date/time...7F 2E 26 0D
Read block 0002 in slot 5, drive 1...succeeded
Sending date/time...7F 2E 26 0D
Read block 0002 in slot 5, drive 1...succeeded
Read block 0003 in slot 5, drive 1...succeeded
Read block 0004 in slot 5, drive 1...succeeded
Read block 0005 in slot 5, drive 1...succeeded

```
could this be caused by using HCT instead of LS? Wasn't able to get LS for some of the chips.

from Apple point of view it works fine, but SSH and Wifi totally suck on single core Zero.

driver version is 29, not listed..
firmware version F
shell version - no idea which shell and how to find out, sorry.

thank you very much.

ps. tried other Apple II+ and Apple IIe, looks like the same problem.

### Hardware Version

Sixth Prototype (Self-assembled)

### Firmware Version

000F

### Driver Version

0028 (add live drive loading and regeneration)

### Shell Version

000D (added version info)

### Where are you seeing this problem?

Other

### What computer is this running on?

Apple II+

tjboldt, 2023-04-03:
The high CPU usage is due to polling the GPIO ports. There is a new version of the hardware in the works that will change this.

tjboldt, 2023-04-04:
I should also say, this has nothing to do with the 74LS chips... It's how polling the GPIO works for now. See #127

JPT77, 2023-11-01:
Great!
Tested on Zero 2 and Zero 1.
Zero 2 25% of one CPU core.
Zero 1 50% CPU.
The biggest problem was that SSH just didn't work well with 100% busy on a single core CPU. So I think this is gonna work fine.
Not sure which Raspberry I used last time, because I cannot connect to my Zero 1. Maybe it's one without wifi. So cannot confirm that it really works better now. Sorry :(

ps. you have to iterate through the update process https://github.com/tjboldt/Apple2-IO-RPi/discussions/65 before you'll see any changes.

tjboldt, 2023-11-01:
Unfortunately I noticed it made keyboard very sluggish and unusable in the shell... So I made another tweak that will go in shortly. It will consume more CPU but not as bad as before the first fix.

Closed 2023-11-01.

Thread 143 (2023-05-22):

Apple2.IO.RPI.hdv - (two) issues

OrangeBox72, 2023-05-22:
### What happened?

On the HDV image (I downloaded on 05/22/2023),

Issue one,
The Basic program "UPDATE.FIRMWARE" seems to be corrupt.
* It shows up in PRODOS w/date (04-MAR-22),
* When I try running it from BitsyBoot, it ABENDs
* When I escape out to BASIC.SYSTEM and load the program,  nothing is there.
* When I use COPYIIPLUS.8.4 (on the HDV), it shows the program as EMPTY (when viewing textually)
* When I use COPYIIPLUS.8.4 (on the HDV), it shows '00 00 00 00 00 00 00 00'  (when viewing values)

Issue two,
In trying to burn the firmware, I hand typed the Basic Program from the gitrepo..
"Apple2-IO-RPi/Apple2/Update.Firmware.bas"

LINE 100 seems to be incorrect..
100  PRINT  CHR$ (4)"BLOAD AT28C64B,A$2000"

The IMAGE FILE on the HDV is  AT28C64B.BIN,  but you reference "AT28C64B"  (sans ".BIN")
attempting to BLOAD as written gives a "PATH NOT FOUND".

I have additional problems, but they are most likely on my side. ;-)

### Hardware Version

Fifth Prototype (Self-assembled)

### Firmware Version

000F

### Driver Version

0028 (add live drive loading and regeneration)

### Shell Version

000D (added version info)

### Where are you seeing this problem?

Other

### What computer is this running on?

Apple //e (enhanced / platinum)

tjboldt, 2023-07-06:
The files are meant to be accessed via the drive itself which admittedly is a little hard if you're just creating one. The dynamic ProDOS volume created by the Apple2-IO-RPi converts the raw ASCII into an AppleSoft BASIC program and the .BIN extension is removed automatically from the AT28C84B.BIN file. I should update the documentation to better explain this.

tjboldt, 2024-05-30:
Documentation updated and firmware added to the release. Closing this issue but if there is something else to change, please reopen this issue or create a new one.

Closed 2024-05-30.

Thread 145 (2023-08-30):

The 3 logic chips can be replaced by a single PLD

rallepalaveev, 2023-08-30:
### What do suggest for improvement?

A potential improvement and decreasing of the chip count would be to use a PLD instead of the 3 logic chips 7400, 7432, 7432.
I have created a design with ATF22V10, which I regularly use - should work :). This is based on the schematics posted on 20 Feb 2022 - Rev 0.6.2.

Here is the PLD source code:

Name     A2-IO-RPi;
PartNo   00;
Date     30/08/2023;
Revision 01;
Designer R.Palaveev;
Company  None;
Assembly None;
Location None;
Device   g22v10;

/** Inputs **/

PIN 1 = A0;
PIN 2 = A1;
PIN 3 = A2;
PIN 4 = A3;
PIN 5 = IOSelect;
PIN 6 = DevSel;
PIN 7 = IOStrobe;
PIN 8 = RW;

/** Outputs **/

PIN 14 = WR;
PIN 15 = CE_U0;
PIN 16 = CE_U4;
PIN 17 = Cp_U5;
PIN 18 = CE_U6;
PIN 19 = Cp_U7;

/**  Logic Equations  **/

WR = !RW;  /**  to pin 1 U0, pin 22 U1  **/

CE_U0 = IOSelect & DevSel;  /**  to pin 19 U0  **/

CE_U4 = WR # A0 # DevSel;  /**  to pin 19 U4  **/

Cp_U5 = RW # A1 # DevSel;  /**  to pin 11 U5  **/

CE_U6 = WR # A2 # DevSel;  /**  to pin 19 U6  **/

Cp_U7 = RW # A3 # DevSel;  /**  to pin 11 U7  **/

tjboldt, 2023-08-30:
What software and hardware do you recommend for programming these chips?

rallepalaveev, 2023-08-30:
I use WinCUPL to write the source code and then compile it to a .jed file. Then I use a TL866-II Plus to burn the chips.
WinCUPL is available on the Microchip website: https://www.microchip.com/en-us/products/fpgas-and-plds/spld-cplds/pld-design-resources#

Closed 2023-09-12.

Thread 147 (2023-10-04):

add read-only jumper please

JPT77, 2023-10-04:
### What do suggest for improvement?

There are circumstances where the first byte of the ROM is overriden.
I got a report, where this happens when CP/M is booted.
I myself experience it every now and then.

A simple solution would be to have a jumper that allows or forbids writing to the EEPROM from the apple.

thank you very much

tjboldt, 2023-10-04:
This is a great suggestion. I'll make up a new board design soon.

JPT77, 2023-10-05:
Until then, here is a workaround that regularly fixes the first byte automatically:
https://forum.classic-computing.de/forum/index.php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

Closed 2024-06-25.

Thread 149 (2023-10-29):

Create your own disk on the fly from directory

JPT77, 2023-10-29:
### What do suggest for improvement?

Hi,

First I wanted to start a discussion, but after analyzing the topic I decided it should be a minor improvement.

I understand that directly booting floppy images is impossible because emulating a floppy drive is impossible out of hardware reasons.

The apple2driver has a mode where it assembles a ProDOS image on the fly from `~/Apple2-IO-RPi/RaspberryPi/driveimage/`

Two issues with this. First it tells:

    This drive is dynamically generated
    from the current working directory on
    the Raspberry Pi and is in RAM only.

which is not true. it is created from `~/Apple2-IO-RPi/RaspberryPi/driveimage/`

Second: I tried passing a directory as parameter to apple2driver, but this did not work. Enhancement?

Not directly related:
how do I provide software into this directory so that I can start it? Extract files from floppy images?

thanks

tjboldt, 2023-10-30:
The ProDOS volume is dynamically generated in RAM on the RPi from the source files held in that directory. The ProDOS volume itself if not stored on disk, just the source files in a Linux directory. You can add files to the directory and it will pick them up next time the ProDOS volume is generated or you can change your configuration to use another directory.

tjboldt, 2023-11-21:
Use the RPI.COMMAND to control the drive images, both from image files and dynamic from a Linux directory:

```
]-rpi.command
]rpi a2drive 1 regen ~/Apple2-IO-RPi/RaspberryPi/driveimage
]rpi a2drive 2 load /home/pi/Games.hdv
```

Closed 2023-11-21.

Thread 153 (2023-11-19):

Shell does not fully work

JPT77, 2023-11-19:
### What happened?

Hi,

I downgraded my Zero2W to ZeroW and somehow it does not connect to wifi any more.
So this is the first time I really use the shell. And it's great on the Apple IIe.

But raspi-config does not work. You can chose an entry but you cannot open it. "Enter" just does nothing. Pressing S or F does not do anything either.
And I think there are a few more things which do not work.

Could you please have a look into it?

thanks

ps. regarding the versions you ask for: Shell shows version E - cannot select below.
how do I run RPI a2version? I don't know the driver version. But I updated everything just now following your guide.

### Hardware Version

Sixth Prototype (Self-assembled)

### Firmware Version

000F

### Driver Version

Older (error calling RPI a2version, pre-2022-Feb-07)

### Shell Version

000D (added version info)

### Where are you seeing this problem?

SHELL command

### What computer is this running on?

Apple //e (enhanced / platinum)

tjboldt, 2023-11-19:
I updated the bug template. Missed adding shell 000E a year ago.

Are you running the latest Raspberry Pi OS? I will see if I can reproduce your issue this weekend.

JPT77, 2023-11-19:
No. Just did an update, but there wasn't much change. Should I upgrade from Debian 11 to Debian 12? Or should I just write a new Raspberry OS image?

tjboldt, 2023-11-19:
I have had problems with just pulling the micro SD card out of a Zero W and putting it into a Zero 2 W but it wasn’t the same issue you’re having. The navigation in the raspi-config was also confusing but that is unrelated and the same in other versions. It has been a while since I tried. Not at my computer now but will have a look when I am.

JPT77, 2023-11-19:
Tried with Raspi 3, same.
Upgraded to Debian 12, same.
Realized there are more problems:
- Enter does not work in NANO menu. have to use VI.
- editing command lines that are wrapped does not work.

tjboldt, 2023-11-20:
Tested... `raspi-config` with VT100 emulation is a bit hard to navigate but it does work... Up and down arrows to choose what you want, then `Tab` to go to the `<Select>` button on the screen, then press `Space`

Alternatively you can configure wifi without the shell...

`]-rpi.command`
`]rpi a2wifi list`
`]rpi a2wifi select SSID PASSWORD REGION`

JPT77, 2023-11-20:
Ah, it's SPACE! But still, nano does not work. Well. Not really important ;)
It wasn't the wifi. Wifi is up and running, but still no network traffic on Zero1W. Still investigating.
Ah and now I understood the rpi commands. thanks for that ;)

Closed 2023-12-05.

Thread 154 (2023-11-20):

Apple2driver does not find GPIOs any more after upgrade to Debian 12

JPT77, 2023-11-20:
### What happened?

Hi,

after upgrading to Debian 12 the apple2driver does not want to come up any more.
how does it access the GPIO hardware?

	Generating Drive in memory from: /home/jan/Apple2-IO-RPi/RaspberryPi/driveimage
	Starting Apple II RPi v002B...
	panic: failed to open gpio
	goroutine 1 [running]:
	github.com/tjboldt/Apple2-IO-RPi/RaspberryPi/apple2driver/a2io.A2Gpio.Init({})
			/home/jan/Apple2-IO-RPi/RaspberryPi/apple2driver/a2io/gpio.go:54 +0x500
	main.main()
			/home/jan/Apple2-IO-RPi/RaspberryPi/apple2driver/driver.go:50 +0xe8
	apple2driver.service: Main process exited, code=exited, status=2/INVALIDARGUMENT
	apple2driver.service: Failed with result 'exit-code'.

I checked everything I could think of, but I found no problem:

	$ ll /dev/gpio*
	crw-rw---- 1 root gpio 254, 0 Nov 19 18:17 /dev/gpiochip0
	crw-rw---- 1 root gpio 254, 1 Nov 19 18:17 /dev/gpiochip1
	crw-rw---- 1 root gpio 241, 0 Nov 20 12:15 /dev/gpiomem

	$ groups
	jan adm dialout cdrom sudo audio video plugdev games users input render netdev gpio i2c spi

	$ cat /etc/systemd/system/apple2driver.service
	[Unit]
	Description=Apple2-IO-RPi Driver

	[Service]
	ExecStart=/home/jan/Apple2-IO-RPi/RaspberryPi/apple2driver/apple2driver
	StandardOutput=journal
	StandardError=journal
	SyslogIdentifier=apple2driver
	User=jan
	Group=jan
	WorkingDirectory=/home/jan/Apple2-IO-RPi/RaspberryPi/apple2driver

	[Install]
	WantedBy=basic.target

Any idea what is wrong?

Thank you very much.

### Hardware Version

Sixth Prototype (Self-assembled)

### Firmware Version

000F

### Driver Version

002B (fix keyboard delay)

### Shell Version

000E (fix hang on exit)

### Where are you seeing this problem?

Boot

### What computer is this running on?

Apple //e (enhanced / platinum)

JPT77, 2023-11-20:
Solved.
It was caused by issuing `sudo rpi-update` while doing debian upgrade.
Several guides recommend doing a rpi-update. But one resource tells this fetches current development kernel and firmware blobs which may be unstable. Firmware and kernel updates should be done automatically by the apt packages upgraded.
I will create a discussion "how to upgrade Rasbian OS"...

Closed 2023-11-20.

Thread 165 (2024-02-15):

Dead after 2 weeks

Vintanerd, 2024-02-15:
### What happened?

Hi, after 2 weeks the card is dead: no more prompt at startup, no boot, when I force a "PR#5" I get the message "CHECK DISK DRIVE".
I tried to move on another slot, to make a new microSD but nothing.
The PiZero is working and accessibile by WiFi.
What's the problem? The Eprom or another chip on the card?

Thanks!
:)

### Hardware Version

Sixth Prototype (lastest classic hardware)

### Firmware Version

0010 (classic hardware)

### Driver Version

002D (add support for RPi Pico hardware)

### Shell Version

800F (initial RPi Pico support)

### Where are you seeing this problem?

Boot

### What computer is this running on?

Apple //e (enhanced / platinum)

tjboldt, 2024-02-17:
It is possible that something else overwrote part of the firmware. See issue #147

tjboldt, 2024-06-25:
Can you check the logs? Is the service running? See #175

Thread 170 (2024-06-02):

Driver crashes accessing drive 2 if no drive image loaded

tjboldt, 2024-06-02:
### What happened?

Boot to ProDOS, do not load a second drive via configuration or RPI.COMMAND, then `CAT,D2`

```
Read block 0002 in slot 7, drive 2...panic: runtime error: invalid memory address or nil pointer dereference
[signal SIGSEGV: segmentation violation code=0x1 addr=0x18 pc=0x111690]

goroutine 1 [running]:
github.com/tjboldt/ProDOS-Utilities/prodos.ReadBlock({0x0, 0x0}, 0x2)
	/home/terence/go/pkg/mod/github.com/tjboldt/!pro!d!o!s-!utilities@v0.4.9/prodos/block.go:20 +0x40
github.com/tjboldt/Apple2-IO-RPi/RaspberryPi/apple2driver/handlers.ReadBlockCommand({0x199720, 0x40000da000}, {0x0, 0x0})
	/home/terence/Apple2-IO-RPi/RaspberryPi/apple2driver/handlers/block.go:43 +0x1b8
main.main()
	/home/terence/Apple2-IO-RPi/RaspberryPi/apple2driver/driver.go:73 +0x218
```

### Hardware Version

Sixth Prototype (lastest classic hardware)

### Firmware Version

0010 (classic hardware)

### Driver Version

002D (add support for RPi Pico hardware)

### Shell Version

Not Applicable (bug not Shell related)

### Where are you seeing this problem?

ProDOS access

### What computer is this running on?

Apple //e (enhanced / platinum)

Closed 2024-06-08.

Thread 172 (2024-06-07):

Garbage from RPI command after update

polileco, 2024-06-07:
### What happened?

Hi,

Thanks for the nice work the project is amazing.

After updating to the firmware 0011 and the 002D driver after booting into ProDOS RPI command does not work and just puts garbage on the screen.

I've pull the project build the a2driver and assemble the commands.

Regards

### Hardware Version

Fifth Prototype (classic hardware without jumper)

### Firmware Version

0010 (classic hardware)

### Driver Version

002D (add support for RPi Pico hardware)

### Shell Version

000D (added version info)

### Where are you seeing this problem?

RPI Command

### What computer is this running on?

Other

tjboldt, 2024-06-07:
Have you rebuilt the RPI.COMMAND and SHELL since upgrading?

`cd ~/Apple2-IO-RPi/Apple2`
`./assemble.sh`

The RPI.COMMAND is likely failing to detect the card as the firmware ID bytes changed.

tjboldt, 2024-06-07:
Oh, and after you reassemble the binaries, you need to refresh the dynamic drive image... Normally I'd suggest using the RPI command to regenerate the drive image but since that's not working for you, maybe on the Linux side, restart the service.

`sudo systemctl restart apple2driver`

Then reboot the Apple II.

polileco, 2024-06-07:
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

Yes. Just for a sanity check did it again, same result.

Running 'rpi ls' from prompt, for example, I got this:

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

Let me know if I can assist you or if more info is needed

Tks

polileco, 2024-06-07:
Oh, 'rpi.command' is executed fine and find the card. The problem arise with the execution of 'rpi' command.

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

Regards

tjboldt, 2024-06-07:
I haven't been able to reproduce the issue the way you're seeing it. I did however find a bug that if you `-rpi.command` after it's already loaded, it echos back in an infinite loop when you try and use `rpi ls` after. I assume it's only loaded once (by the startup.bas)?

polileco, 2024-06-07:
> I haven't been able to reproduce the issue the way you're seeing it. I did however find a bug that if you `-rpi.command` after it's already loaded, it echos back in an infinite loop when you try and use `rpi ls` after. I assume it's only loaded once (by the startup.bas)?

Yes. Letting my tests to bare bone. Only the IO-RPi on slot 6 and using de default drive image from the project.

tjboldt, 2024-06-07:
Okay, put everything exactly the way you have it in slot 6 with no other cards other an extended 80 column card and I see the problem. I'll try and make a fix as soon as possible.

polileco, 2024-06-07:
> Okay, put everything exactly the way you have it in slot 6 with no other cards other an extended 80 column card and I see the problem. I'll try and make a fix as soon as possible.

Tks! Let me know if i can help in some way.

With IO-RPi in another slot the problem persist? I can try this weekend.

Regards

tjboldt, 2024-06-07:
Side note... It was working in slot 7 as that is the default... The code that was setting the slot number on detection was off by 256 bytes because the detection code got bigger and pushing into the next page. I had to fix the offset by one.

Closed 2024-06-07.

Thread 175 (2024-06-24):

GPIO errors on startup

tjboldt, 2024-06-24:
### What happened?

CygnusTM reported:

The apple2driver.service fails on autostart every time the Pi reboots. Then it will work fine if I restart the service

```
todd@raspberrypi:~ $ sudo systemctl status apple2driver.service
× apple2driver.service - Apple2-IO-RPi Driver (Classic edition)
     Loaded: loaded (/etc/systemd/system/apple2driver.service; enabled; preset: enabled)
     Active: failed (Result: exit-code) since Mon 2024-04-29 10:49:28 EDT; 56s ago
   Duration: 777ms
    Process: 392 ExecStart=/home/todd/Apple2-IO-RPi/RaspberryPi/apple2driver/apple2driver (code=exited, status=2)
   Main PID: 392 (code=exited, status=2)
        CPU: 226ms

Apr 29 10:49:28 raspberrypi apple2driver[392]: Starting Apple II RPi v002D...
Apr 29 10:49:28 raspberrypi apple2driver[392]: Starting communications via GPIO ports...
Apr 29 10:49:28 raspberrypi apple2driver[392]: panic: failed to open gpio
Apr 29 10:49:28 raspberrypi apple2driver[392]: goroutine 1 [running]:
Apr 29 10:49:28 raspberrypi apple2driver[392]: github.com/tjboldt/Apple2-IO-RPi/RaspberryPi/apple2driver/a2io.A2Gpio.Init({})
Apr 29 10:49:28 raspberrypi apple2driver[392]:         /home/todd/Apple2-IO-RPi/RaspberryPi/apple2driver/a2io/gpio.go:54 +0x3d0
Apr 29 10:49:28 raspberrypi apple2driver[392]: main.main()
Apr 29 10:49:28 raspberrypi apple2driver[392]:         /home/todd/Apple2-IO-RPi/RaspberryPi/apple2driver/driver.go:60 +0x148
Apr 29 10:49:28 raspberrypi systemd[1]: apple2driver.service: Main process exited, code=exited, status=2/INVALIDARGUMENT
Apr 29 10:49:28 raspberrypi systemd[1]: apple2driver.service: Failed with result 'exit-code'.
```

dkgeorge also had this issue:

Was having the same issue and included the line below the [Service] section of /etc/systemd/system/apple2driver.service

```
[Service]
ExecStartPre=/bin/sleep 30
```

This fixed the problem. Apparently apple2driver.service was attempting to start too early during boot.

### Hardware Version

Sixth Prototype (lastest classic hardware)

### Firmware Version

0010 (classic hardware)

### Driver Version

002D (add support for RPi Pico hardware)

### Shell Version

000F (classic hardware support)

### Where are you seeing this problem?

Boot

### What computer is this running on?

Apple //e (enhanced / platinum)

tjboldt, 2024-06-25:
@dkgeorge I did some digging and it seems there are quite a few dependencies to put into the file if I wanted to add `After=` so I think your suggestion of `Type=idle` is best. If you want to show up as a contributor, you could fork, add that line to `RaspberryPi/setup.sh` in two places and make a pull request. If not, I'll make the change and just add you to the thanks in the readme.

```
diff --git a/RaspberryPi/setup.sh b/RaspberryPi/setup.sh
index 51de4f8..18e4195 100644
--- a/RaspberryPi/setup.sh
+++ b/RaspberryPi/setup.sh
@@ -58,6 +58,7 @@ sudo --preserve-env=HOME --preserve-env=USER bash -c 'cat > apple2driver.service
 Description=Apple2-IO-RPi Driver (Pico edition)

 [Service]
+Type=idle
 ExecStart=$HOME/Apple2-IO-RPi/RaspberryPi/apple2driver/apple2driver -cdc=true
 StandardOutput=syslog
 StandardError=syslog
@@ -75,6 +76,7 @@ sudo --preserve-env=HOME --preserve-env=USER bash -c 'cat > apple2driver.service
 Description=Apple2-IO-RPi Driver (Classic edition)

 [Service]
+Type=idle
 ExecStart=$HOME/Apple2-IO-RPi/RaspberryPi/apple2driver/apple2driver
 StandardOutput=syslog
 StandardError=syslog
 ```

tjboldt, 2024-06-25:
Fixed with #177

Closed 2024-06-25.

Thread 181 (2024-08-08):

Meta key in -SHELL

sethkush, 2024-08-08:
### What do suggest for improvement?

Would it be possible to make one of the apple keys work as meta when using -SHELL?
Currently Esc works, but it's not as good as a dedicated meta key.

tjboldt, 2024-08-09:
Thanks for the explanation... Currently the project is using VT100 terminal emulation rather than something like xterm-256color etc. I don't see how I'd send the alt/meta key escape code in VT100. Maybe I'm missing something. It's possible to support other terminal emulation but it would be a lot of work. Here are the VT100 codes I'm aware of:

https://espterm.github.io/docs/VT100%20escape%20codes.html

If you can find how to escape the ALT key codes in VT100, adding code to detect the Apple key is easy. Otherwise, I can start looking at other terminal emulation in the future.

sethkush, 2024-08-24:
According to this https://xn--rpa.cc/irl/term.html the alt key actually just sends ESC quickly followed by whatever it's combined with, so I think it would be simple to implement within the VT100 escape codes since ESC already works.

tjboldt, 2024-08-28:
@sethkush Thanks for the explanation and links. I tried sending ESC-character from the Apple II assembly code but this apparently wasn't fast enough for the terminal to pick it up as a meta character. Instead, when the Open-Apple key is pressed, I send the character without stripping the high bit. On the RaspberryPi end, if it sees the high bit set, it clears it and then sends ESC plus the character. This seems to be working for me now.

Closed 2024-08-28.

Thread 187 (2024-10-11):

issue on boot

g91, 2024-10-11:
### What happened?

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
hello my friend I'm curious if you've ever seen this before and how to fix it this is happening whenever the machine is turned on and the card is attempted to be accessed. machine was working fine for many hours turned it off came back turned it back on then this issue. c702- a=20 x=00 y=FF P=B5 S=F9

### Hardware Version

Seventh Prototype (lastest classic hardware)

### Firmware Version

0011 / 8011 (add clock driver)

### Driver Version

0030 (add support for meta key)

### Shell Version

0011 (add support for meta key)

### Where are you seeing this problem?

Boot

### What computer is this running on?

Apple //e (enhanced / platinum)

tjboldt, 2024-10-12:
Depending on which other cards and software you run, it is possible to accidentally overwrite the firmware on the Apple2-IO-RPi card. Since you have a v7 board, you can change the jumpers to put the EEPROM in read-only mode. I'd recommend trying to rewrite the firmware, then set the jumpers for read-only mode. Actually, you might want to try that with only the A2IORPi card in the system to ensure it doesn't get messed up. Then after it's read-only, put everything back in and fire it up.

g91, 2024-10-13:
I bought the card pre-assembled can you tell me of a good eprom programmer that I could use.

tjboldt, 2024-10-13:
If the card has the AT28C64B chip on it, you can actually use the Apple II to program the firmware, although it will only program for the slot that the card is located in. After rewriting the firmware, I'd recommend setting the jumper to make it read-only.

g91, 2024-10-14:
would it be possible to get the Flasher onto a floppy image   I did something wrong and now I'm getting this error after shell      Apple2-IO-RPi not found

tjboldt, 2024-10-14:
It looks like it's still booting and you have a valid drive image. The `Apple2-IO-RPi` not found error is likely caused by corrupt firmware bytes. Try running `-UPDATE.FIRMWARE`, then set the jumper to read-only mode after. Also, best to try this with no other cards in the system in case there is a conflict and something else tries to write to the EEPROM space.

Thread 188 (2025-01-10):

RPi FW stuck on OK

omigeot, 2025-01-10:
### What happened?

Upon booting on the RPi card's slot, it waits for RPi FW (0011), then prints OK then ... that's all, it's stuck on this for ages. If I ssh to the Pi, the logs only show heaps of : `apple2driver[303]: Read block 0000 in slot 6, drive 1...succeeded` (always on block 0000). The apple2driver process is stuck at 100% CPU.

A little context : I've got my IIGS back from the basement and it hasn't run in a while. So I updated Apple2-IO-RPi while I was at it. Didn't work, ran setup.sh again on the Pi. Booted but kept stuck on "Apple2-IO-Rpi not found" ; according from a related issue's details, I ran -UPDATE.FIRMWARE again, and this time everything worked flawlessly for a couple hours.

Then, out of nowhere, after one restart, I got the current behaviour, described up there.

Note : since I can't boot on Rpi anymore, I'm not sure how I could check a2version or the shell version...

### Hardware Version

Sixth Prototype (classic hardware power jumper)

### Firmware Version

0011 / 8011 (add clock driver)

### Driver Version

0030 (add support for meta key)

### Shell Version

0011 (add support for meta key)

### Where are you seeing this problem?

Boot

### What computer is this running on?

Apple IIgs

tjboldt, 2025-01-12:
Block 0000 is the ProDOS boot loader. I can imagine one of two things failing there. Either something overwrote part of your firmware or if you’re using a disk image rather than the in-memory dynamic generated disk, maybe something overwrote that block on your image. There have been a few people with issues of firmware being damaged so in the latest revision of the hardware, a jumper was added to set the EEPROM to read only mode.

omigeot, 2025-01-12:
So, if I'm understanding right : block 0000 could either (A) come from a file on the RPi's filesystem, or (B) from the EEPROM on the board, right?

If that's so, I suppose I could easily test whether it's (A) by just changing the file it's pointing to (in my case, it's a symlink, so an extra-easy task). If that's not improving situation, it's probably (B), and my EEPROM content is damaged. Which leads me to following question : what are my ways to fix it? is it doable from the board, or do I need extra-hardware?

tjboldt, 2025-01-13:
Block 0000 is not on the EEPROM, it's either in a file on your RPi or generated in the RPi's RAM depending on how you configured it. Let me know if you need help figuring that out. The EEPROM might be fine but it's possible it's corrupted and preventing it from loading the full block and executing it. If the EEPROM is at fault, you can reprogram it without special hardware but you'll need to be able to get the firmware and firmware updater onto a floppy disk to run it there. Unfortunately that's easier to do if you already had the A2IORPi running. There are other creative ways to get files over to an Apple II but will take some effort.

omigeot, 2025-01-13:
> Unfortunately that's easier to do if you already had the A2IORPi running.

Am I wrong, or would I be able to re-flash the EEPROM using something like that? https://github.com/gfoot/picoprom

(which, as far as I'm concerned, is basically "without special hardware")

felangga, 2025-02-22:
Same here, mine stuck on OK then do nothing.
The RPI log only shows this logs
```
Feb 22 03:18:20 raspberrypi apple2driver[330]: Generating Drive in memory from: /home/felangga/Apple2-IO-RPi/RaspberryPi/driveimage
Feb 22 03:18:21 raspberrypi apple2driver[330]: Starting Apple II RPi v0030...
Feb 22 03:18:21 raspberrypi apple2driver[330]: Starting communications via GPIO ports...
```

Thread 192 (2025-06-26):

Programs like neofetch do not render in Linux shell

DanBrownleeOps, 2025-06-26:
### What happened?

Enter -shell to Linux
neofetch
programs begins but I believe ansi screen command get into a loop and can't recover back to Linux prompt.
It works, however, if the same command is run from a tmux session, first.

### Hardware Version

RPi Pico

### Firmware Version

0010 / 8010 (initial RPi Pico hardware)

### Driver Version

0030 (add support for meta key)

### Shell Version

0011 (add support for meta key)

### Where are you seeing this problem?

SHELL command

### What computer is this running on?

Apple II

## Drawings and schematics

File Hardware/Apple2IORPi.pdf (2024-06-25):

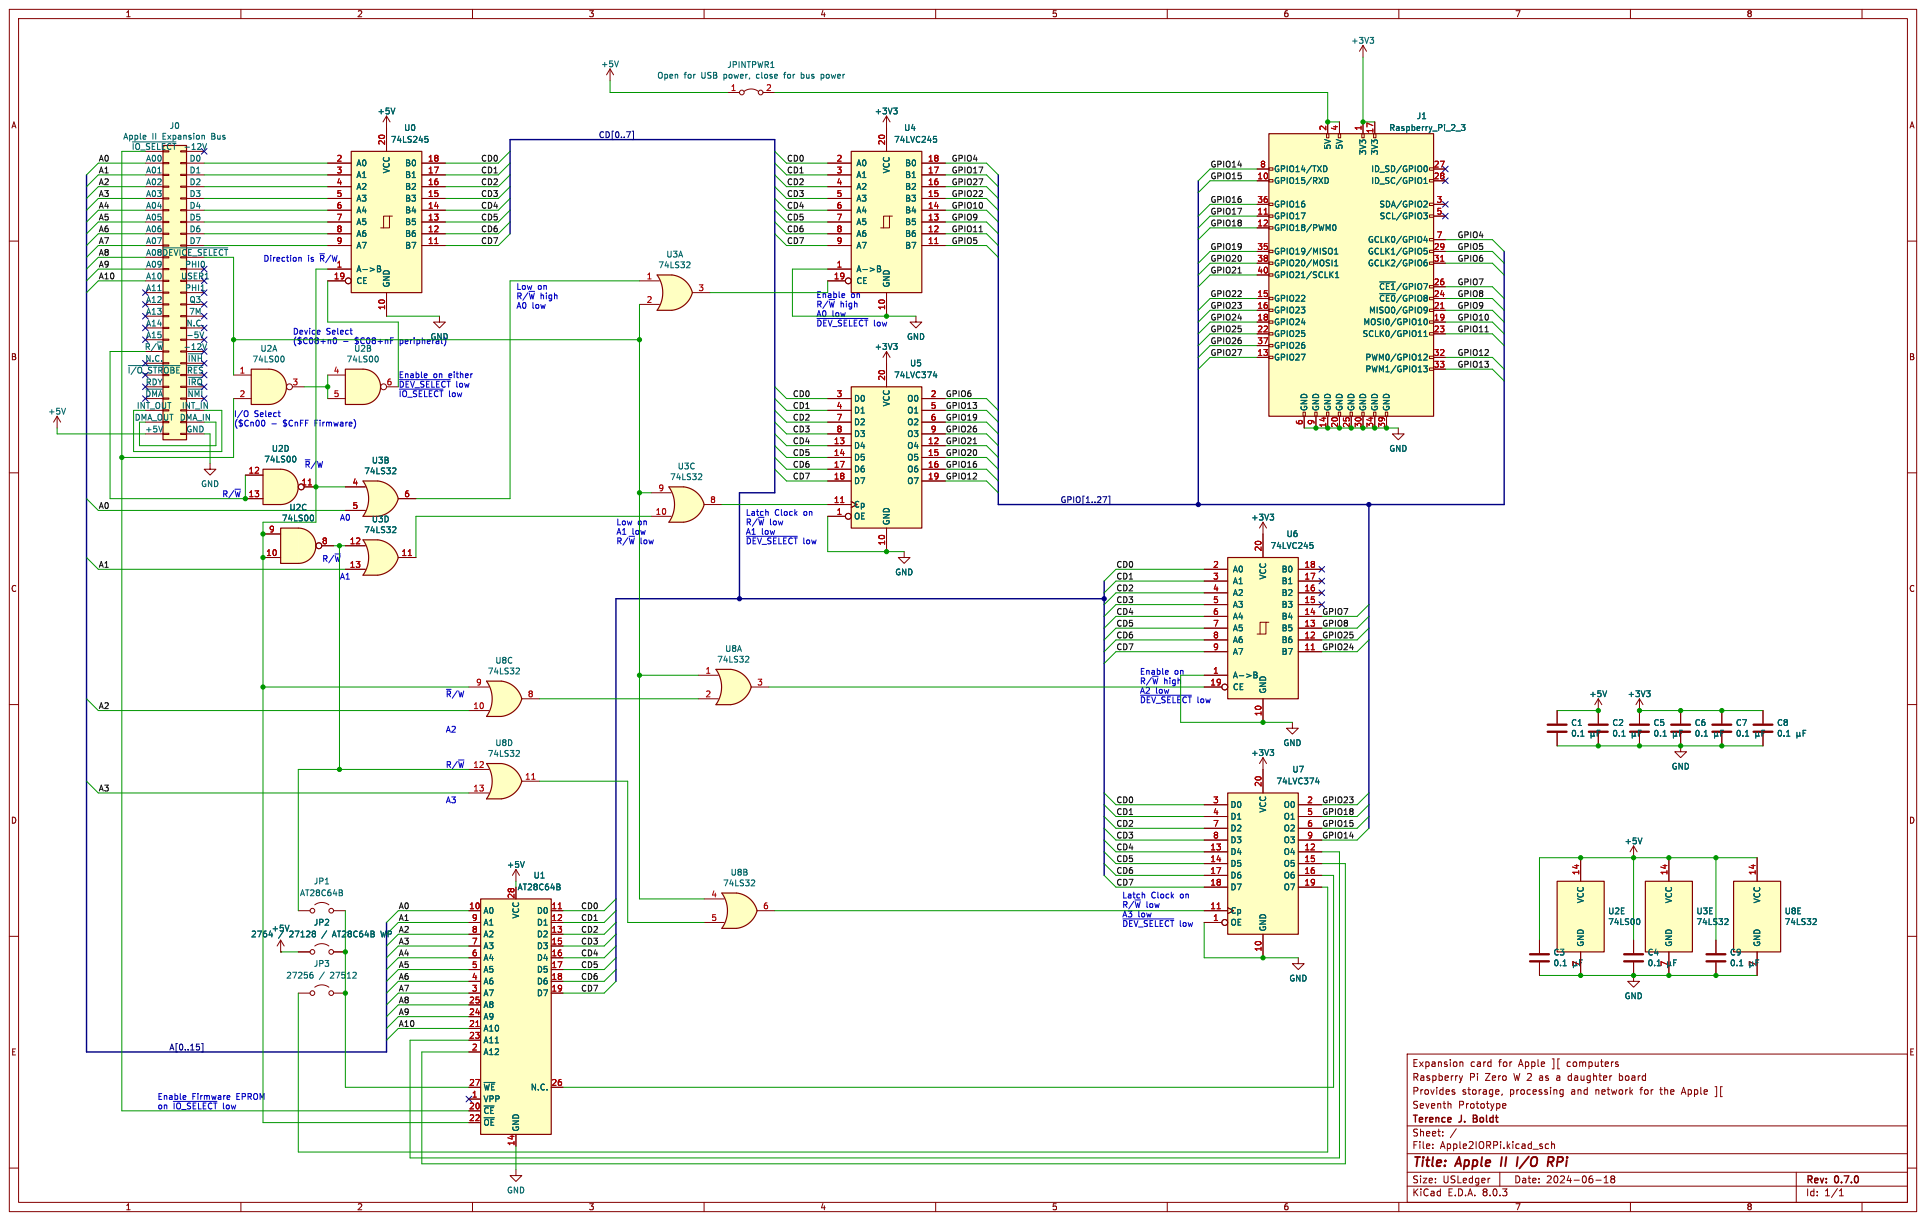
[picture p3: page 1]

JPINTPWR1 Open for USB power, close for bus power +5V

Low on R/~{W}high A0 low

Enable on R/~{W}high A0 low

Latch Clock on R/~{W}low

Enable on R/~{W}high A2 low

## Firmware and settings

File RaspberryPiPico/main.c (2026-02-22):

/*

MIT License

Copyright (c) 2022 Oliver Schmidt (https://a2retro.de/)

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
*/

#include <stdio.h>
#include <pico/printf.h>
#include <pico/stdlib.h>
#include <pico/multicore.h>
#include <hardware/clocks.h>
#include <hardware/structs/busctrl.h>

#include "board.h"

#ifdef TRACE
void uart_printf(uart_inst_t *uart, const char *format, ...) {
    static char buffer[0x100];

    va_list va;
    va_start(va, format);
    vsnprintf(buffer, sizeof(buffer), format, va);
    va_end(va);

    buffer[0xFF] = '\0';
    uart_puts(uart, buffer);
}
#endif

void main(void) {
    busctrl_hw->priority = BUSCTRL_BUS_PRIORITY_PROC1_BITS;
    multicore_launch_core1(board);

    set_sys_clock_khz(200000, false);

    stdio_init_all();
    stdio_set_translate_crlf(&stdio_usb, false);

    gpio_init(PICO_DEFAULT_LED_PIN);
    gpio_set_dir(PICO_DEFAULT_LED_PIN, GPIO_OUT);

#ifdef TRACE
    uart_init(uart0, 115200);
    uart_set_translate_crlf(uart0, true);
    gpio_set_function(PICO_DEFAULT_UART_TX_PIN, GPIO_FUNC_UART);
    gpio_set_function(PICO_DEFAULT_UART_RX_PIN, GPIO_FUNC_UART);
#endif

    while (true) {
        bool conn = stdio_usb_connected();
        if (conn) {
            if (multicore_fifo_rvalid()) {
                uint32_t data = multicore_fifo_pop_blocking();
                putchar(data);
#ifdef TRACE
                uart_printf(uart0, "> %02X\n", data);
#endif
            }
        }

        if (multicore_fifo_wready()) {
            int data = getchar_timeout_us(0);
            if (data != PICO_ERROR_TIMEOUT) {
                multicore_fifo_push_blocking(data);
#ifdef TRACE
                uart_printf(uart0, "< %02X\n", data);
#endif
            }
        }

        gpio_put(PICO_DEFAULT_LED_PIN, conn);
    }
}

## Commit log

2020-11-03 Add initial schematic - MISSING RESISTORS AND CONTROL LINES
    [Apple2IORPi.kicad_pcb, Apple2IORPi.sch]
2020-11-11 Add control lines and resistors - STILL MISSING CAPACITORS AND VCC/GND
    [Apple2IORPi.sch]
2020-11-16 Update schematic and create rough PCB layout
    [Apple2IORPi.kicad_pcb, Apple2IORPi.sch]
2020-11-17 Update PCB component layout
    [Apple2IORPi.kicad_pcb, Apple2IORPi.sch]
2020-11-19 Update schematics and board - Remove resistor voltage dividers - Change to 74LVC parts with +3.3V VCC - Remove control lines
    [Apple2IORPi.kicad_pcb, Apple2IORPi.sch]
2020-11-19 Update PCB footprints and layout
    [Apple2IORPi.kicad_pcb]
2020-11-19 Complete initial PCB layout
    [Apple2IORPi.kicad_pcb]
2020-11-19 Update README.md with current project status
2020-11-19 Update PCB images
2020-11-19 Update power and ground wiring
    [Apple2IORPi.kicad_pcb]
2020-11-19 Generate gerber and drill files
    [Apple2IORPi-B_Cu.gbr, Apple2IORPi-B_Mask.gbr, Apple2IORPi-B_SilkS.gbr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]
2020-11-20 Remove unnecessary vias
    [Apple2IORPi.kicad_pcb]
2020-12-05 Add test assembler code to match Go and Node.js code
2020-12-07 Add RAM based ProDOS driver for testing
2020-12-08 Fix device unit bug in Driver
2020-12-10 Fix device list with y instead of a
2020-12-10 Add Raspberry Pi driver code
2020-12-13 Add unused slot 0 to offset EPROM correctly
2020-12-13 Fix firmware build for slot 5
2020-12-13 Add ground wires to EPROM address lines
    [Apple2IORPi-B.Cu.gbr, Apple2IORPi-B.Mask.gbr, Apple2IORPi-B.SilkS.gbr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]
2020-12-14 Update schematic/PCB to work with more EPROM types
    [Apple2IORPi-B.Cu.gbr, Apple2IORPi-B.Mask.gbr, Apple2IORPi-B.SilkS.gbr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]
2020-12-14 Update board image with EPROM
2020-12-14 Update gerber files
    [Apple2IORPi-B.Cu.gbr, Apple2IORPi-B.Mask.gbr, Apple2IORPi-B.SilkS.gbr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]
2020-12-16 Add file sync to prevent data loss on power-off
2020-12-30 Update board to support 8 bit data and 16x firmware
    [Apple2IORPi-B.Cu.gbr, Apple2IORPi-B.Mask.gbr, Apple2IORPi-B.SilkS.gbr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]
2020-12-30 Optimize vias and tracks
    [Apple2IORPi-B.Cu.gbr, Apple2IORPi-B.Mask.gbr, Apple2IORPi-B.SilkS.gbr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]
2020-12-30 Clean up tracks
    [Apple2IORPi-B.Cu.gbr, Apple2IORPi-B.Mask.gbr, Apple2IORPi-B.SilkS.gbr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]
2021-01-09 Remove unused line
    [Apple2IORPi.sch]
2021-01-11 Fix silkscreen issue where chips mislabelled
    [Apple2IORPi-B.Cu.gbr, Apple2IORPi-B.Mask.gbr, Apple2IORPi-B.SilkS.gbr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]
2021-01-16 Update RPi driver to support full byte read/write
2021-03-14 Update board to support AT28C64B
    [Apple2IORPi-B.Cu.gbr, Apple2IORPi-B.Mask.gbr, Apple2IORPi-B.SilkS.gbr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]
2021-03-16 Update PCB image
2021-03-24 Update image to fourth prototype
2021-03-28 Updated driver to support working directory
2021-05-30 Remove driver executable
2021-07-02 Assembler clean-up
2021-07-28 Remove jumpers and EPROM support
    [Apple2IORPi-B_Cu.gbr, Apple2IORPi-B_Mask.gbr, Apple2IORPi-B_SilkS.gbr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]
2021-07-28 Update README for fifth revision of board
2021-07-28 Update images for 5th prototype
    [Apple2IORPi.kicad_pcb]
2021-09-28 Allow force lower case commands (Issue #15)
2021-10-07 Fix firmware and driver to support drive 2
2021-10-31 Add assembler github action
2021-10-31 Copy assembler binary
2021-10-31 Add ld65 config
    [none.cfg]
2021-10-31 Add exit on failure of assemble.sh
2021-10-31 Force assembly failure to test GitHub action
2021-10-31 Test GitHub Action successful assembly
2021-12-31 Add slot detection for Shell
2022-02-07 Auto-detect slot number for RPI.COMMAND
2022-02-17 Add power jumper and instructions
    [Apple2IORPi-B_Cu.gbr, Apple2IORPi-B_Mask.gbr, Apple2IORPi-B_SilkS.gbr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]
2022-02-17 Update README for sixth prototype
2022-02-18 Update to KiCAD 6
    [Apple2IORPi-B_Cu.gbr, Apple2IORPi-B_Mask.gbr, Apple2IORPi-B_SilkS.gbr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]
2022-02-18 Add no-connects to open pins
    [Apple2IORPi.kicad_sch]
2022-02-18 Make ERC pass
    [Apple2IORPi.kicad_sch]
2022-02-18 Ignore KiCAD backups
2022-02-18 Apple II connector pin names and directions
    [Apple2IORPi.kicad_sch]
2022-02-18 Remove power wires, improve signal names
    [Apple2IORPi.kicad_sch]
2022-02-18 Add data bus
    [Apple2IORPi.kicad_sch]
2022-02-18 Add power nets
    [Apple2IORPi.kicad_sch]
2022-02-19 Reconnect EEPROM CE correctly, tweaks
    [Apple2IORPi.kicad_sch]
2022-02-20 Fix AT28C64D pins, add GPIO bus
    [Apple2IORPi.kicad_sch]
2022-02-20 Fix warnings and errors in PCB
    [Apple2IORPi-B_Cu.gbr, Apple2IORPi-B_Mask.gbr, Apple2IORPi-B_Silkscreen.gbr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]
2022-02-20 Clean up ERC warnings/errors
    [Apple2IORPi.kicad_pcb, Apple2IORPi.kicad_sch]
2022-02-21 Update pdf to latest schematic
    [Apple2IORPi.kicad_sch]
2022-02-21 Clean up buses for aesthetics
    [Apple2IORPi.kicad_sch]
2022-03-01 Fix #95 gerber render for PCBWay compatibility
    [Apple2IORPi-B_Cu.gbr, Apple2IORPi-B_Mask.gbr, Apple2IORPi-B_Silkscreen.gbr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]
2022-03-04 Update RPi.Command and driver for it
2023-01-09 Update driver version
2023-03-01 Update schematics for 0.1 µF caps (#136)
    [Apple2IORPi.kicad_sch]
2023-03-08 Add bill of materials
    [BOM.csv]
2023-03-08 Update schematic PDF
2023-11-01 Add backoff to reduce CPU usage (fixes #141) (#151)
    * Add backoff to reduce CPU usage
    * Update driver version for CPU fix
2024-02-06 Initial Pico hardware support
    * Added assemble.cmd for Windows.
    In the long run, some (c)make-based cross-plafrom solution seems preferable.
    * Fill up the menu page just like the other pages.
    * Allow to assemble for different hardware types.
    The first script parameter is used to set the ca65 symbol HW_TYPE. Without parameter, HW_TYPE is set to 0.
    * Avoid unwanted i/o access.
    Depending on the 6502, LDA addr,X and/or STA addr,X produce additional phantom reads. In order to avoid those phantom reads to do i/o access, I used the "classic" approach of moving those reads from page $C0 to page $BF.
    * Made use of BIT instruction to access InputFlags from firmware.
    Doing the s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
2024-03-29 Fix Pico build
2024-04-18 Add clock driver, remove from firmware (#168)
2024-06-08 Fix #170 driver crash on unload drive
2024-06-25 Update to hardware revision 7 (#176)
    * Add jumpers for write protect and EPROMs
    * Update to latest hardware revision 7
    [Apple2IORPi-B_Cu.gbr, Apple2IORPi-B_Mask.gbr, Apple2IORPi-B_Silkscreen.gbr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]
2024-08-28 Update dependencies (#184)
    * Update dependencies
    * Update driver version
2025-05-22 Update driver dependencies
